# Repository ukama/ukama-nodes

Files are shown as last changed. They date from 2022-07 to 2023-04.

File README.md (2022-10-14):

# ukama-nodes
This repo contains all of the Ukama hardware stuff. This includes the products, modules there in and instruction on how to build one. 

Currently the repo is organized as "electronics", "mechanics" and "products" 

## Electronics:

This contains all the electronics board (PCBs) used in various Ukama products. Currently, the electronics includes:

gpp - general purpose processing board (use in Tower Node)

ctrl - Controller board for the FE (front-end) (use in Amplifier Unit) 

fe - front-end (use in Amplifier Unit)

mask - add-on extension board for the Tower Node

mini_trx - small RAN (base-station) and is used in Home Node

trx - RAN and is used in Tower Node

Each of the eletronics has assembly, BoM, layout, placement, schematic and stencil info. 

## Mechanics:

This contains all the mechanics (CADs) for all of the Ukama products. Currently. it includes the assembly, CAD, drawings, heatsinks (if any) and gaskets (if any). 

## Products:

This contains all the product level information. This include, currently, the system-level BoM and artwork (if any.)

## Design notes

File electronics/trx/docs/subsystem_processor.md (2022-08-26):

#### Processor

LTE-SoC processor used in TRX module is CNF7130 from Marvell. It is MIPS64 based Quad core System-on-chip with below features: 
* Core frequency up to 1.3GHz and Co-processor frequency up to 800MHz
* High-bandwidth fully coherent on-chip memory system including a 1MB 16-way set-associative L2 cache
* A 72-bit DDR3 DRAM interface, up to 1066 MHz data rate
* Integrated Baseband processing module containing three radio-processing clusters: 
    * An uplink symbol radio-processing cluster, 
    * An uplink soft-bit radio processing cluster, 
    * A downlink radio processing cluster

Below diagram provides high level information about internal modules of LTE-SoC:

processor

The Local Memory Controller (LMC) DDR3 SDRAM controller conforms to the JEDEC DDR3 SDRAM specification. 
Up to 32GB DDR3 RAMs can be connected to LMC SDRAM controller. In TRX module, 4GB DDR3 RAM is used with Data rates up to 1066 MHz.

The Level-2 Cache Controller (L2C) has shared on-chip cache memory which is shared be all of the cores and I/O components on LTE-SOC. 

Shared main memory (implemented via the level-2 cache and the DRAM) is the primary communication media for bulk transfers in the LTE-SoC. 

Level-2 cache is shared by all of the CPU cores instructions/data and hardware device DMA accesses. The L2 cache can be partitioned, and can be bypassed on a reference-by-reference basis. I/O devices can DMA data directly into L2 cache.

##### LTE-SoC Internal Clock Architecture

LTE-SoC has a single reference clock signal (PLL_REF_CLK) that feeds into three PLLs (Core PLL, Co-processor PLL and DDR PLL) that provide the clock signals for the rest of the chip.
Each PLL has its own set of PLL_REF_CLK multipliers, allowing each to generate its own frequency.

The Core PLL generates the core clock, which is used by the MIPS cores. The frequency is configured by using pin straps during Reset release. PLL_MUL_[4:0] pins are used as below: 

| PLL_MUL[4:0] | Clock Frequency |
|---|---|
| 0x02 | 400MHz |
| 0x06 | 600MHz |
| 0x0A | 800MHz |
| 0x0E | 1.0GHz |
All other options are reserved

The Coprocessor PLL generates the coprocessor clock, which is used by the rest of the coprocessors and the I/O interfaces. The frequency is determined by pin straps connected to SYS_PLL_MUL_[4:0] pins and are listed as below:

| SYS_PLL_MU[4:0] | Clock Frequency |
|---|---|
| 0x02 | 400MHz |
| 0x06 | 600MHz |
| 0x0A | 800MHz |
All other options are reserved

Below diagram shows the internal clock scheme of LTE-SoC:

processor-clock

Notes:-
      w : SMI_CLK[PHASE]  

QLM0 Serdes clock will be derived from an external source. In TRX module, a spread spectrum clock generator IC is used as source which will produce a clock of 100MHz.

Whereas, QLM1 Serdes clock can be either derived from an external source or from QLO0 reference clock. In TRX module, QLM0 reference clock is used to source QLM1 Serdes also. 

USB PLL will have a dedicated crystal connected to its  XO and XI pins.

Note that the core clock, the coprocessor clock, the DDR3 clock, and the PCIe interface have the following interdependencies:
* the core-clock frequency must be greater than or equal to the coprocessor-clock frequency
* the core-clock frequency must be greater than or equal to the DDR3-clock frequency
* PCIe Gen II requires a coprocessor-clock frequency of 600 MHz.

##### Boot process

LTE-SoC implements a boot-bus interface that can be interfaced with NOR, eMMC, or SD flash devices. In TRX module, NOR flash is used as primary boot device and eMMC memory is used as additional storage device. 
There are 8 Chip selects and 32bit Address/Data lines in boot bus.
When configured in 8bit data width option, BOOT_AD[31:24] is the data bus.
The boot bus consumes a 4GB portion of the LTE-SoC physical-address (PA) space range from 0x1 0000 0000 0000 to 0x1 0000 FFFF FFFF. 
In TRX module, Chip select 0 (CE_0) is connected to NOR Flash for primary booting purpose. 
LTE-SoC maps PA space to 0x1 0000 1FC0 0000 for CE_0.
Boot code should be present in the NOR flash starting at boot address 0. When the LTE-SoC self-boots, core 0 executes this code immediately following chip-reset de-assertion. 
The pin straps that LTE-SoC uses for configuration are shown below:
| Pin Strap | Comment |
|---|---|
| BOOT_AD[15] | An external pull-up resistor changes region 0 from nonmultiplexed (i.e. nonALE mode) to multiplexed (i.e. ALE) mode. |
| BOOT_AD[14] | An external pull-up resistor changes region 0 from eight-bit data width to 16-bit data width |
| BOOT_AD[12] | An external pull-up resistor changes the default polarity of BOOT_DMACK1 from active-high to active-low |
| BOOT_AD[11] | An external pull-up resistor changes the default polarity of BOOT_DMACK0 from active-high to active-low |
| BOOT_AD[10:9] | External pull-up resistors that change the boot-bus-driver drive strength in the following manner: <br /> [00] : Full strength <br /> [01] : 20 ohm <br /> [10] : 50 ohm <br /> [11] : 60 ohm |
| BOOT_AD[8] | When an external pull-down resistor is connected, SoC will boot from NOR Flash |
| BOOT_AD[7:0]  | When using eMMC, BOOT_AD[7:0] is EMMC_DAT[7:0]. |

##### GPIO 

The GPIO bus is a collection of general-purpose pins that can be configured for various tasks, and is a low-speed bus. Each pin can be configured as input, output, clock-like output, level-sensitive/edge-triggered interrupt pins. 

In TRX module, GPIO's are used for different purposes as listed in below table : 

| GPIO # | DIR  | Default state | Connected to | Functionality |
|:---:|:---:|:---:|:---:|:---:|
| 0 | Out  | 1 | LED | General purpose LED |
| 1 | In | 0 | Temperature Sensor | Critical temperature alert |
| 2 | Out  | 1 | JTAG header | JTAG Soft reset |
| 3 | Out  | 0 | Ethernet Switch  | Ethernet SYNCE |
| 4 | In | 0 | GPS module | GPS time pulse |
| 5 | Out  | 0 | Watchdog timer | Watchdog Input |
| 6 | In | 0 | COM module | Power good of COM module |
| 7 | In | 0 | Mask module | Interrupt from Mask module |
| 8 | Out  | 0 | eMMC | Dedicated pin to enable eMMC |
| 9 | In | 0 | Switch | High indicates LTE-SoC is I2C master<br> Low indicates COM module is I2C master |
| 10 | In/Out | 0 | COM module | General purpose I/Os from COM module |
| 11 | In | 0 | Connector | External 1pps reference input |
| 12 | Out  | 0 | COM module | COM module power recycle |
| 13 | In/Out | 0 | COM module | General purpose I/Os from COM module |
| 14 | In/Out | 0 | COM module | General purpose I/Os from COM module |
| 15 | In | 0 | COM module | Platform Reset information from COM module |
| 16 | In | 0 | I2C switch | TRX module I2C interrupt |
| 17 | In | 0 | COM module | COM module I2C interrupt |
| 18 | In | 1 | Reset switch | Push button reset input |
| 19 | Out  | 1 | Reset | System reset out from LTE-SoC |

##### Debug

LTE-SoC has multiple debug features, including:
* Two UARTs for connection to an external console.
* Full core support for the MIPS EJTAG standard, including single-step and an external JTAG interface with one internal TAP controller per core.

In TRX module, a provision is been made to connect EJTAG connector. 
Main debug port is UART0. Boot logs during system boot will be transmitted through UART0 port at 115200 baud rate. 
TX and RX pins of UART0 is connected to an isolator and then connected to USB to UART converter IC to have a mini-B USB connector as debug port.
The 5V required by the converter IC is derived from the USB connector. 

Optionally, UART1 signals are also brought to a 3 pin header. 

processor-debug

##### SerDes

The PCIe and SGMII interfaces are shared SerDes interfaces of LTE-SoC. The SerDes interface is made up of two two-lane modules (DLM0 and DLM1). 
The DLMs have the following configurations:
* DLM0: 2× SGMII/1000 Base-X
* DLM1: PCIe (one ×2 or 2 ×1)

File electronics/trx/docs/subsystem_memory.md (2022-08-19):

###Memory Sub-system

####DDR RAM

The LTE-SoC has an internal LMC DDR3 SDRAM controller which conforms to the JEDEC DDR3 SDRAM specification. A total of 4 DDR3 ICs, with 512MB density each are connected to provide a memory capacity of 4GB. One additional DDR3 IC is provided for SECDED ECC purpose. 

DDR3 memory architecture is as shown below: 

DDR

DDR subsystem operates at a voltage of 1.35V. 72bit (64bit data + 8bit ECC) bus is configured to work with data transfer rate at 1066MHz.

Below table lists out different DDR signals and their functionality:

| Signal Name | Direction  | Description |
|---|---|---|
| **_ Rank 0 – Data Signal Group _** | | |
| DDR_DQ[63:0] | In/Out | Data Bus |
| DDR_DQSP[7:0], DRAM0_DQSN[7:0] | In/Out | Data Strobes |
| DDR_CB[7:0] | In/Out | ECC Data Bits |
| DDR_CBS0P, DDR_CBS0N | In/Out | ECC Data Strobes |
| **_ Rank 0 – Command Signal Group _** | | |
| DDR_A[15:0] | Out | Memory Address Bus |
| DDR_BA[2:0] | Out | Bank Select |
| DDR_RAS# | Out | Row Address Select |
| DDR_CAS# | Out | Column Address Select |
| DDR_WE# | Out | Write Enable |
| **_ Rank 0 – Control Signal Group _** | | |
| DDR_DIMM0_CS0_L | Out | Chip Select (one per rank) |
| DDR_DIMM0_CKE0 | Out | Clock Enable (one per rank). |
| DDR_DIMM0_ODT0 | Out | On-Die Termination Select/Enable |
| **_ Rank 0 – Clock Signal Group _** | | |
| DDR_CK0P | Out | Differential Clocks |
| DDR_CK0N | Out | Inverted Differential Clocks |
| **_ DDR3L Reference and Compensation Signals _** | | |
| DDR_VREF | In | SDRAM Reference Voltage: external reference voltage input for each system margining |
| DDR_PLL_VDD33 | In | DDR3L Power Good Monitor. |
| DDR_RESET_L | Out | DDR3L DRAM Reset. |
| DDR_COMP_DP DDR_COMP_DN | In/Out | DDR3L Compensation signals |

The termination scheme for DDR signals is as shown below:

DDR Termination

#### NOR Flash

TRX module is equipped with a 128MB parallel NOR flash which is configured as primary boot device. This Asynchronous memory will work with a supply voltage of 3.3V. 

Below diagram illustrates the NOR flash connection with LTE-SoC:

NOR

Voltage compatibility of NOR flash with LTE-SoC is as follows:

##### High Level Noise Margin:

| Source  | Destination  | Voh (min) | Vih (min) | Noise margin  |
|---|---|---|---|---|
| LTE-SOC | NOR flash | 2.6 | 2.31 | 0.29 |

##### Low Level Noise Margin:
| Source | Destination | Vol (max) | Vil (max) | Noise margin |
|---|---|---|---|---|
| LTE-SOC | NOR flash | 0.7 | 0.8 | 0.1 |

##### High Level Noise Margin:
| Source | Destination | Voh (min) | Vih (min) | Noise margin |
|---|---|---|---|---|
| NOR flash | LTE-SOC | 2.805 | 2.31 | 0.495 |

##### Low Level Noise Margin:
| Source | Destination | Vol (max) | Vil (max) | Noise margin |
|---|---|---|---|---|
| NOR flash | LTE-SOC | 0.495 | 0.825 | 0.33 |

##### High Level Noise Margin:
| Source | Destination | Voh (min) | Vih (min) | Noise margin |
|---|---|---|---|---|
| LTE-SOC | Latch | 2.6 | 2.0 | 0.6 |

##### Low Level Noise Margin:
| Source | Destination | Vol (max) | Vil (max) | Noise margin |
|---|---|---|---|---|
| LTE-SOC | Latch | 0.7 | 0.8 | 0.1 |

##### High Level Noise Margin:
| Source | Destination | Voh (min) | Vih (min) | Noise margin |
|---|---|---|---|---|
| Latch | NOR flash | 3.1 | 2.31 | 0.79 |

##### Low Level Noise Margin:
| Source | Destination | Vol (max) | Vil (max) | Noise margin |
|---|---|---|---|---|
| Latch | NOR flash | 0.55 | 0.8 | 0.25 |

#### eMMC

Additional storage option is provided in TRX module in the form of eMMC memory IC which is complaint with eMMC Specification Ver 5.1. 

eMMC memory architecture is as shown below:

eMMC

Data bus of eMMC IC is connected to LTE-SoC via shared boot bus. Clock signal is derived from CE_5 pin of LTE-SoC and Command signal is derived from CE_1 pin of LTE-SoC

All the MMC signals are connected to eMMC device via a FET Switch which acts as level shifter and is enabled through GPIO_8 from LTE-SoC. 
A Complimentary pair enhancement mode MOSFET is used to control the power supply of eMMC which is also driven from GPIO_8 from LTE-SoC.

Voltage compatibility of eMMC with LTE-SoC is as follows:

##### High Level Noise Margin:

| Source  | Destination  | Voh (min) | Vih (min) | Noise margin  |
|---|---|---|---|---|
| LTE-SOC | FET Switch | 2.6 | 2.31 | 0.29 |

##### Low Level Noise Margin:
| Source | Destination | Vol (max) | Vil (max) | Noise margin |
|---|---|---|---|---|
| LTE-SOC | FET Switch | 0.7 | 0.8 | 0.1 |

##### High Level Noise Margin:
| Source | Destination | Voh (min) | Vih (min) | Noise margin |
|---|---|---|---|---|
| FET Switch | LTE-SOC | 2.805 | 2.31 | 0.495 |

##### Low Level Noise Margin:
| Source | Destination | Vol (max) | Vil (max) | Noise margin |
|---|---|---|---|---|
| FET Switch | LTE-SOC | 0.495 | 0.825 | 0.33 |

##### High Level Noise Margin:
| Source | Destination | Voh (min) | Vih (min) | Noise margin |
|---|---|---|---|---|
| FET Switch | eMMC | 2.6 | 2.0 | 0.6 |

##### Low Level Noise Margin:
| Source | Destination | Vol (max) | Vil (max) | Noise margin |
|---|---|---|---|---|
| FET Switch | eMMC | 0.7 | 0.8 | 0.1 |

##### High Level Noise Margin:
| Source | Destination | Voh (min) | Vih (min) | Noise margin |
|---|---|---|---|---|
| eMMC | FET Switch | 3.1 | 2.31 | 0.79 |

##### Low Level Noise Margin:
| Source | Destination | Vol (max) | Vil (max) | Noise margin |
|---|---|---|---|---|
| eMMC | FET Switch | 0.55 | 0.8 | 0.25 |

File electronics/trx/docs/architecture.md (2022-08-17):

####Architecture overview

TRX module is based on a LTE-SoC along with RF Transceiver. 
Below diagram represents the high level architecture overview of TRX module: 

high level architecture diagram 

A detailed representation of TRX module subsystems along with their interfaces is as shown below:

detailed architecture diagram

CNF7130 from Marvell is used as LTE-SoC in TRX module. It will have 4GB DDR3 memory as RAM connected via DDR3 bus of LTE-SoC, 128MB NOR Flash and 32GB eMMC memories connected to Boot bus of LTE-SOC acts as storage devices. 
AD9363 from Analog is used as RF Transceiver which is connected to LTE-SoC via two ports of 12bit data bus along with control signals. 
An Ethernet switch from Marvell 88E6341, acts as bridge between LTE-SoC, COM Module and External RJ45 connector. 
A GPS module and an OCXO along with DAC are used to cater for timing requirements of TRX module.

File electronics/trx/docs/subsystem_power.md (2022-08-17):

###Power overview

####Power tree

TRX module is powered with IEEE 802.3bt Type 4 Class 8 PoE. A PD controller is used along with dual ideal diode bridge controller to receive power from  data/spare pairs of ethernet cable. PD controller is configured to convert 50-57V of PoE supply to 12V DC supply which will be input supply for the TowerNode system. A provision of connecting DC supply from external power source is also made. In scenarios where both PoE and external DC supply are connected, system will disable PoE and considers external DC supply only. 

Below diagram represents the power architecture of TRX module:

power tree

Input supply,12V goes through a PMBus/I2C complaint controller to measure, protect and control the electrical operating conditions. 
Protected 12V supply is provided to COM module, mask module and is also converted to 5V from a step-down DC/DC converter. 5V is then converted to various supplies like 3.3V through a step down converter, 1.1V for LTE-SoC through a buck converter and 1.35V for LTE-SoC through a step down converter. 
3.3V is a major supply for TRX module and is used for LTE-SoC, NOR Flash, eMMC, Ethernet PHY, OCXO, GPS module, sensors and EEPROMs. Secondary supplies of LTE-SoC such as 1.5V, 1.8V and VTT supply for DDR memories are generated from 3.3V supply through voltage regulators. 1.8V is further converted to 1.3V required for RF Transceiver through a LDO. 

####Power Sequence

Power sequence of TRX module is as shown below: 

--Power sequence diagram to be inserted here -- 

High level Power sequence followed in TRX module design is in the order of System supplies -> LTE-SoC -> DDR -> System Reset release. 

System input supply 12V is converted to 5V initially with a time delay of 10ms. The step-down converter used to convert 5V to 3.3V will have a delay of 5ms. 
Once 3.3V is stable, the 3.3V power good signal asserted from step-down converter will drive enable pins of buck/dtep-down converters of LTE-SoC power supplies(1.8V, 1.5V and 1.1V). 

A stable 1.1V will assert power good signal from buck converter which is used to enable remaining power supplies of LTE-SoC (1.35V and VTT).

The 1.35V power good is then delayed by 150ms to ensure LTE-SoC and other peripherals are in powered-up state before releasing the Reset. 

####Power Dissipation

Below table lists out the maximum power dissipated by major ICs in TRX module: 

| Sl.No. | Component P/N | Description | Manufacturer | Power (W) |
|---|---|---|---|---|
| 1 | CNF7130-1000BG772-G | Cavium OCTEON Fusion CNF7130 | Cavium | 18 |
| 2 | IS43TR16256AL-15HBLI-ND | 4Gbit DDR3L SDRAM, FBGA 96 | ISSI | 0.405 |
| 3 | IS43TR16256AL-15HBLI-ND | 4Gbit DDR3L SDRAM, FBGA 96 | ISSI | 0.405 |
| 4 | IS43TR16256AL-15HBLI-ND | 4Gbit DDR3L SDRAM, FBGA 96 | ISSI | 0.405 |
| 5 | IS43TR16256AL-15HBLI-ND | 4Gbit DDR3L SDRAM, FBGA 96 | ISSI | 0.405 |
| 6 | IS43TR16256AL-15HBLI-ND | 4Gbit DDR3L SDRAM, FBGA 96 | ISSI | 0.405 |
| 7 | 88E6341 | Gigabit Energy Switch | Marvell | 0.726 |
| 8 | MLC1260-401MLB | Fixed Inductors Power Inductor 0.4 uH 20 % | Coilcraft | 0.103 |
| 9 | VLF10045T-2R2N7R4 | INDUCTOR POWER 2.2UH 6.3A SMD,±30% | TDK | 0.1632 |
| 10 | ASPI-0530HI-1R5M-T2 | INDUCTOR POWER 1.5UH 5A SMD +/-20% | Abracon Corporation | 0.125 |
| 11 | PI6C557-03BLE | IC CLOCK GENERATOR 16TSSOP | Pericom | 0.33 |
| 12 | TPS53353DQPT | IC REG BUCK SYNC ADJ 20A 22 pin QFN | TI | 0.55 |
| 13 | TPS54620RGYR | Synchronous Step-down Voltage Converter 6A | TI | 1.08 |
| 14 | AP3418KTR-G1 | 1500mA Step-Down Regulator Adjustable | Diodes Inc | 0.1125 |
| 15 | TPS54519RTET | IC REG BUCK SYNC ADJ 5A 16WQFN | TI | 0.72 |
| 16 | BGA824N6 | The BGA824N6 is a front-end low noise amplifier | infineon | 0.198 |
| 17 | AD9363ABCZ | RF Transceiver | Analog Device | 1.874 |
| 18 | LTM8056EY#PBF | IC MOD BUCK REG 58VIN 121BGA | Linear Technology | 3.5 |
| 19 | LMZ14203HTZX/NOPB | IC BUCK SYNC ADJ 3A TO-PMOD-7 | TI | 1.3 |
| 20 | TPS7A7300RGWR | IC REG LDO FIX/ADJ 3A 20VQFN | TI | 0.96 |
| 21 | TPS7A7300RGWR | IC REG LDO FIX/ADJ 3A 20VQFN | TI | 0.32 |
| 22 | TPS7A7300RGWR | IC REG LDO FIX/ADJ 3A 20VQFN | TI | 1.19 |

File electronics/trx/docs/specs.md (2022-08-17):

####Operational requirements
TRX Board along with a COM board comprises as TowerNode system. The TowerNode system is designed to meet the following requirements:

•	Powered by IEEE 802.3bt PoE (71.3 Watt Max)
•	Interface to the backhaul is over a RJ45 (Gigabit Ethernet) interface
•	Interface to the RF Front End (AmplifierNode) through cables connected over the SMA connector
•	Maximum RF output from TowerNode is -14dBm

####Environmental requirements
The TowerNode system is designed to operate at below environmental conditions

•	Ambient temperature: -20 °C to +50 °C
•	Altitude: Up to 20,000 feet
•	Solar load: Max 1100W/m2

####Hardware features
•	TowerNode is compliant with IEEE 802.3bt standard Powered Device with maximum power rating of 71.3W. 
•	TowerNode system architecture comprises of two modules: TRX and COM
•	TRX module is based on a LTE-SoC from Marvell which is used for Baseband processing
•	LTE-SoC is a quad core MIPS64 processor with Uplink/Downlink hardware accelerators
•	TRX module has below memory options:
  --	4GB DDR3L as RAM memory
  --	128MB NOR Flash as boot storage
  --	32GB eMMC as main storage
  --	Two 256Kb EEPROMs for configuration and inventory purposes

•	TRX module will have a default configuration switch that will enable the user to reset the Tower Node to factory settings.
•	A push button reset provision is provided on TRX module for user to perform system reset or to reset the Tower Node to factory defaults state.
•	TRX module will have several temperature sensors to enable measuring of temperature near the hot spots.
•	There are four RGB LEDs provided to indicate the status of the system as per implementation. 
•	TRX module is protected for over voltage, under voltage, over current, ESD
•	A generic GPS module is accommodated for timing requirements. 
•	Optional Mask module can be connected to TRX module via mask connector based on the system requirements. Different types of Mask module can be used such as Connectivity, Storage etc.

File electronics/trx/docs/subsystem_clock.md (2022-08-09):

###Clock/Reset Overview

####Clock tree

Several clock sources are used in TRX module to cater for clock requirements of the system. Below diagram represents the clock architecture used in TRX module:

---Clock tree to be inserted -- 

Oscillators are used as core clock reference for CNF7130, Ethernet switch and Clock generator IC. 
A 12MHz crystal is used as USB reference clock for CNF7130
In order to support timing requirement of AD9363, an OCXO,U7769LF is used from Rakon. This can be tuned via an analog signal at control voltage input pin. Analog voltage is generated by using a DAC(DAC8571) controlled from CNF7130

####Reset tree

Reset architecture used in TRX module is as shown below:

--Reset tree to be inserted--

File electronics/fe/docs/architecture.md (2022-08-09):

##Transmitter test case procedure
1.	Set the BS as per the test setup as per the setup diagram shown above.
2.	Start with 10MHz channel bandwidth for Top, Middle and Bottom channel frequency.
3.	Configure the board TRX switching by enabling TX mode (by making TRX_SWIT_CNTRL High)
4.	Run the command “./dl_pltd.sh 1 0001 1.1 2” to transmit signal according to ETM 1.1 test model.
5.	Measure the mean output power from spectrum analyzer.

Run the scipi command to measure the Mean output power from spectrum analyzer 
Commands need to update
6.	Repeat the above test steps for Middle and Bottom channel frequencies.
7.	Repeat the above test steps for the Antenna port 1.
8.	Ensure the test results (power level, ACLR, SEM) is as per the test requirement as per expected.
9.	SEM test case setup need to update.

| Sl.No. | Description | PartNumber | Qty | Value |
|---|---|---|-----|---|
| 1 | | | | |
| 2 | | | | |
| | | | | |

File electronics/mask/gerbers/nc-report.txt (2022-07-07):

(---------------------------------------------------------------------)
(                                                                     )
(    NC DRILL Log                                                     )
(                                                                     )
(    Drawing          : #Taaaaai09524.tmp                             )
(    Software Version : 16.6P004                                      )
(    Date/Time        : Mon May 16 22:51:13 2022                      )
(                                                                     )
(---------------------------------------------------------------------)

 Processing NC Parameters file 'nc_param.txt' ...

 NC PARAMETERS
 -------------

 FORMAT   		5.5
 MACHINE-OFFSET		x:0.000000	y:0.000000
 FEEDRATE		1
 COORDINATES		ABSOLUTE
 OUTPUT-UNITS		ENGLISH
 TOOL-ORDER		INCREASING
 REPEAT-CODES		YES
 SUPPRESS-LEAD-ZEROES	NO
 SUPPRESS-TRAIL-ZEROES	NO
 SUPPRESS-EQUAL		NO
 TOOL-SELECT		YES
 HEADER			none
 LEADER			12
 CODE			ASCII
 SEPARATE		NO
 SEPARATE-ROUTING	NO
 OPTIMIZE_DRILLING	NO
 ENHANCED_EXCELLON	YES
 SCALE			1.000000

 WARNING(SPMHMF-358): Design precision is the same as that of the drill output file data.
 WARNING(SPMHMF-359): Data rounding errors may still be possible.
 WARNING(SPMHMF-368): Cannot find NC Drill tool file 'nc_tools.txt'
 WARNING(SPMHMF-369): ... will auto-generate tool file 'nc_tools_auto.txt'.

     Auto-generating tool file 'nc_tools_auto.txt' ...

           Size  Plating  Tool        + Tolerance  - Tolerance

          10.00  P        T01            3.000000     3.000000
          39.37  P        T02            3.000000     3.000000
          39.40  P        T03            3.000000     3.000000
          42.91  P        T04            0.000000     0.000000
          47.20  P        T05            3.000000     3.000000
          55.12  P        T06            3.000000     3.000000
          62.99  P        T07            3.000000     3.000000
         145.70  P        T08            3.000000     3.000000
          20.00  N        T09            3.000000     3.000000
          43.00  N        T10            3.000000     3.000000
          44.00  N        T11            3.150000     3.150000
          64.00  N        T12            1.970000     1.970000

 Drill files being output to directory 'E:/Mask Board/WORK/16-05-22' ...

     'mask-C2-RevC-1-4.drl' created for holes connecting TOP and BOTTOM
     ------------------------------------------------------------------

     Tool  Num     Size      +/- Tolerance     Plating   Quantity

     T01    1.  10.0000    3.0000/  3.0000      PLATED        551
     T02    2.  39.3700    3.0000/  3.0000      PLATED          2
     T03    3.  39.4000    3.0000/  3.0000      PLATED          4
     T04    4.  42.9100    0.0000/  0.0000      PLATED          5
     T05    5.  47.2000    3.0000/  3.0000      PLATED          4
     T06    6.  55.1200    3.0000/  3.0000      PLATED          4
     T07    7.  62.9900    3.0000/  3.0000      PLATED          4
     T08    8. 145.7000    3.0000/  3.0000      PLATED          3
     T09    9.  20.0000    3.0000/  3.0000  NON_PLATED          8
     T10   10.  43.0000    3.0000/  3.0000  NON_PLATED          8
     T11   11.  44.0000    3.1500/  3.1500  NON_PLATED          4
     T12   12.  64.0000    1.9700/  1.9700  NON_PLATED          4

     ---- Total holes:                                        601

     ---- Total head travel:              35.58 feet (10.85 meters)

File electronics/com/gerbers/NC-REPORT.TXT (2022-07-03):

(---------------------------------------------------------------------)
(                                                                     )
(    NC DRILL Log                                                     )
(                                                                     )
(    Drawing          : COM_V1_P2_21-12-2020_4.brd                    )
(    Software Version : 16.6-2015S108                                 )
(    Date/Time        : Fri Dec 25 11:43:52 2020                      )
(                                                                     )
(---------------------------------------------------------------------)

 Processing NC Parameters file 'nc_param.txt' ...

 NC PARAMETERS
 -------------

 FORMAT   		5.5
 MACHINE-OFFSET		x:0.00000	y:0.00000   (inch)
 FEEDRATE		1
 COORDINATES		ABSOLUTE
 OUTPUT-UNITS		ENGLISH
 TOOL-ORDER		INCREASING
 REPEAT-CODES		YES
 SUPPRESS-LEAD-ZEROES	NO
 SUPPRESS-TRAIL-ZEROES	NO
 SUPPRESS-EQUAL		NO
 TOOL-SELECT		YES
 HEADER			none
 LEADER			12
 CODE			ASCII
 SEPARATE		NO
 SEPARATE-ROUTING	NO
 OPTIMIZE_DRILLING	NO
 ENHANCED_EXCELLON	YES
 SCALE			1.000000

 WARNING(SPMHMF-360): Design precision is greater than that of the drill output file data.
 WARNING(SPMHMF-361): Data rounding errors are very possible.
 WARNING(SPMHMF-368): Cannot find NC Drill tool file 'nc_tools.txt'
 WARNING(SPMHMF-369): ... will auto-generate tool file 'nc_tools_auto.txt'.

     Auto-generating tool file 'nc_tools_auto.txt' ...

           Size  Plating  Tool        + Tolerance  - Tolerance

          8.000  P        T01            3.000000     3.000000
         10.000  P        T02            3.000000     3.000000
         12.000  P        T03            3.000000     3.000000
         39.370  P        T04            3.000000     3.000000
         43.000  P        T05            3.000000     3.000000
         47.244  P        T06            3.000000     3.000000
        145.669  P        T07            3.000000     3.000000
         19.685  N        T08            3.150000     3.150000

 Drill files being output to directory 'E:/CAD/CAD/FACEBOOK/COM V1/WORK/21-12-20' ...

     'COM_V1_P2-1-10.drl' created for holes connecting TOP and BOTTOM
     ----------------------------------------------------------------

     Tool  Num     Size      +/- Tolerance     Plating   Quantity

     T01    1.   8.0000    3.0000/  3.0000      PLATED       2348
     T02    2.  10.0000    3.0000/  3.0000      PLATED         75
     T03    3.  12.0000    3.0000/  3.0000      PLATED         99
     T04    4.  39.3700    3.0000/  3.0000      PLATED          4
     T05    5.  43.0000    3.0000/  3.0000      PLATED          2
     T06    6.  47.2440    3.0000/  3.0000      PLATED          4
     T07    7. 145.6690    3.0000/  3.0000      PLATED          6
     T08    8.  19.6850    3.1500/  3.1500  NON_PLATED         24

     ---- Total holes:                                       2562

     ---- Total head travel:              155.52 feet (47.40 meters)

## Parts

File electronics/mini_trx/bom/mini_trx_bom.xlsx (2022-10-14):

Item | Quantity | Reference | Part Number | Manufacturer | Description | Value
1 | 3 | C1,C5,C19 | 202R18W102KV4E | Johanson Dielectrics Inc. | CAP CER 1000PF 2KV X7R 1206 | 1000PF
2 | 2 | C3,C4 | 101X43W474MV4E | Johanson Dielectrics Inc | CAP CER 0.47UF 100V X7R 1812 | 0.47UF
3 | 229 | C6,C25,C31,C41,C57,C58,C59,C60,C61,C63,C64,C65,C66,C67,C68,C69,C70,C71,C72,C73,C74,C75,C81,C82,C83,C84,C85,C86,C87,C88,C89,C90,C92,C97,C98,C99,C100,C101,C102,C103,C104,C105,C107,C108,C109,C110,C112,C113,C114,C115,C116,C117,C118,C119,C120,C121,C122,C123,C124,C125,C126,C127,C128,C129,C130,C135,C136,C137,C138,C139,C154,C157,C158,C163,C164,C165,C176,C181,C182,C202,C204,C210,C214,C243,C244,C247,C248,C251,C254,C255,C256,C258,C259,C263,C264,C269,C271,C272,C274,C275,C277,C278,C279,C280,C281,C282,C283,C286,C287,C288,C289,C290,C291,C292,C294,C296,C297,C298,C299,C302,C303,C304,C305,C306,C307,C308,C309,C310,C311,C312,C313,C314,C315,C316,C317,C318,C324,C325,C326,C327,C328,C329,C330,C332,C333,C334,C335,C336,C337,C338,C339,C340,C341,C342,C343,C344,C346,C347,C348,C349,C350,C351,C352,C353,C354,C355,C356,C357,C358,C359,C360,C361,C362,C363,C364,C365,C366,C369,C373,C378,C388,C389,C390,C391,C392,C401,C402,C403,C404,C405,C406,C407,C408,C413,C415,C418,C420,C423,C424,C428,C429,C431,C432,C433,C434,C435,C438,C439,C459,C462,C604,C605,C616,C619,C621,C622,C623,C624,C625,C628,C629,C630,C631,C632,C633,C634,C637,C638,C639 | C1005X7R1E104K050BB | TDK Corporation | CAP CER 0.1UF 25V 10% X7R 0402 | 0.1uF
4 | 72 | C26,C43,C76,C95,C96,C106,C111,C134,C141,C156,C159,C160,C166,C167,C168,C170,C177,C178,C179,C200,C238,C239,C241,C249,C252,C257,C260,C261,C262,C268,C270,C273,C293,C319,C320,C321,C322,C323,C331,C345,C367,C371,C380,C383,C393,C394,C396,C398,C410,C412,C414,C421,C430,C437,C440,C445,C446,C448,C449,C450,C461,C464,C601,C602,C603,C617,C618,C620,C627,C636,C641,C659 | GRM188C81C106MA73D | Murata | CAP CER 10UF 16V X6S 0603 | 10uF
5 | 6 | C28,C52,C53,C54,C55,C400 | GRM31CR60J107ME39L | Murata Electronics | CAP CER 100UF 6.3V 20% X5R 1206 | 100uF/6.3V
6 | 7 | C29,C77,C203,C225,C226,C411,C417 | GRM188R61A226ME15D | Murata Electronics | CAP CER 22UF 10V 20% X5R 0603 | 22uF/10V
7 | 3 | C30,C94,C436 | CC0402KRX7R7BB103 | Yageo | CAP CER 10000PF 16V 10% X7R 0402 | 10nF
8 | 12 | C35,C131,C132,C140,C144,C145,C171,C399,C409,C416,C456,C606 | CC0402KRX7R8BB102 | Yageo | CAP CER 1000PF 25V X7R 0402 | 1000pF
9 | 15 | C37,C152,C169,C172,C211,C276,C395,C397,C611,C612,C613,C614,C626,C635,C640 | CC0402KRX5R8BB105 | Yageo | CAP CER 1UF 25V X5R 0402 | 1uF
10 | 2 | C40,C222 | GRT155R61E474ME01D | Murata Electronics | CAP CER 0.47UF 25V X5R 0402 | 0.47uF
11 | 1 | C48 | TMK325ABJ476MM-P | Taiyo Yuden | CAP CER 47UF 25V X5R 1210 | 47uF/25V
12 | 1 | C49 | TPSE687K006R0045 | AVX Corporation | CAP TANT 680UF 10% 6.3V 2917 | 680uF
13 | 2 | C62,C79 | C0402C220J3GACTU | KEMET | CAP CER 22PF 25V C0G/NP0 0402 | 22pF
14 | 6 | C80,C91,C284,C455,C600,C615 | GRM1555C1H200JA01D | MURATA | CAP CER 20PF 50V 5% NPO 0402 | 20pF
15 | 1 | C93 | CC0402KRX7R8BB102 | Yageo | CAP 1000PF 25V CERAMIC 0402 SMD | 1000pF
16 | 14 | C146,C147,C149,C150,C161,C162,C173,C174,C422,C425,C426,C427,C465,C466 | C0402C330J4RACAUTO | KEMET | CAP CER 0402 33PF 16V X7R 5% AUT | 33pF
17 | 1 | C201 | C0402C182J3GAC7867 | KEMET | CAP CER 1800PF 25V NP0 0402 | 1.8nF
18 | 2 | C206,C651 | GRM033R61C104KE84D | Murata Electronics | CAP CER 0.1UF 16V X5R 0201 | 0.1uF
19 | 1 | C215 | CC0402KRX7R7BB222 | Yageo | CAP CER 2200PF 16V X7R 0402 | 2.2nF
20 | 1 | C220 | GRM155R61E225ME15D | Murata Electronics | CAP CER 2.2UF 25V X5R 0402 | 2.2uF
21 | 1 | C231 | EEE-FK1A221XP | Panasonic | CAP TANT 680UF 4V 10% LOESR SMD | 220uF/10V
22 | 4 | C245,C246,C250,C253 | CC0402KRX7R8BB102 | Yageo | CAP 10000PF 16V CERAMIC 0402 SMD | 1000pF
23 | 1 | C266 | CC0402KRX7R8BB332 | YAGEO | CAP CER 3300PF 25V X7R 0402 | 3.3nF
24 | 1 | C368 | GRM155C81E105KE11D | Murata | CAP CER 1UF 25V X6S 0402 | 1UFX_16V
25 | 13 | C370,C372,C374,C375,C376,C377,C379,C381,C382,C384,C385,C386,C387 | GRM033R61E104ME14D | Murata Electronics North America | CAP CER 0.1UF 25V X5R 0201 | 0.1UFX
26 | 1 | C419 | 04023A3R3CAT2A | AVX Corporation | CAP CER 3.3PF 25V NP0 0402 | 3.3pF
27 | 4 | C442,C443,C458,C463 | C0402C101K3RAC7867 | KEMET | CAP CER 100PF 25V X7R 0402 | 100pF
28 | 50 | R10,R2N1,R2N2,L42,L43,R108,R120,R121,R160,R166,R180,R184,R199,R201,R233,R234,R239,R241,R288,R300,R370,R372,R378,R384,R395,R401,R409,R414,R439,R444,R445,C453,C454,R465,R466,R468,R469,R470,R471,R472,R473,R561,R562,R565,R566,R606,R614,R616,R619,R620 | RC0402JR-070RL | Yageo | RES SMD 0 OHM JUMPER 1/16W 0402 | 0
29 | 2 | C607,C609 | EMVE250ADA470MF55G | United Chemi-Con | CAP ALUM 47UF 20% 25V SMD | 47uF
30 | 1 | C608 | CC0201KRX5R8BB103 | Yageo | CAP CER 10000PF 25V X5R 0201 | 0.01uF
31 | 2 | C650,C652 | GRM1555C1H270JA01D | Murata Electronics | CAP CER 27PF 50V C0G/NP0 0402 | 27pF
32 | 2 | C657,C658 |  | Murata Electronics | CAP CER 10UF 25V X7S 0805 | 10uF
33 | 5 | D1,D2,D3,D4,D5 | PESD3V3X1BL,315 | Nexperia USA Inc. | TVS DIODE 3.3V SOD882 | PESD3V3X1BL,315
34 | 1 | D6 | RB751S40T5G | ON Semiconductor | DIODE SCHOTTKY 40V 30MA SOD523 | RB751S40T5G
35 | 1 | D27 | B530C-13-F | Diodes Incorporated | DIODE SCHOTTKY 30V 5A SMC | B530C-13-F
36 | 1 | D28 | SMBJ16CA | Littelfuse Inc | TVS DIODE 16VWM 26VC SMB | SMBJ16CA
37 | 3 | FB18,FB19,FB20 | BLM18PG330SN1D | Murata Electronics North America | FERRITE BEAD 33 OHM 0603 1LN | 33E
38 | 1 | J5 | 77313-818-14LF | Amphenol ICC (FCI) | CONN HEADER VERT 14POS 2.54MM | HEADER 7X2
39 | 1 | J7 | 5000751517 | Molex | CONN RCPT USB2.0 MINI B VERT | MINI-USB TYPE A/B CON
40 | 4 | J11,J18,J19,J20 | U.FL-R-SMT-1(10) | Hirose Electric Co Ltd | CONN U.FL RCPT STR 50 OHM SMD | U.FL
41 | 1 | J12 | 7498111120AR | Würth Elektronik | CONN JACK 1PORT 1000 BASE-T SMD | 7498111120AR
42 | 1 | J22 | PJ-051AH | CUI Inc. | 2.0 mm Center Pin, 5.0 A, Right Angle, Through Hole, Shielded, Dc Power Jack Connector | PJ-051AH
43 | 1 | J23 | M55-7102042R | Harwin | CONN HEADER SMD R/A 20POS 1.27MM | M55-7102042R
44 | 1 | LED2 | LTST-C190TBKT | LITEON | LED Blue Clear 0603 | Blue
45 | 1 | LED4 | LTST-C190KRKT | LITEON | LED Red Clear 0603 | Red
46 | 4 | LED11,LED12,LED13,LED14 | XZCCBDMEDGK161W | SunLED | 2.5X0.7MM LC RGB RIGHT ANGLE SMD | XZCCBDMEDGK161W
47 | 4 | LED19,LED20,LED21,LED22 | LTST-C190KGKT | LITEON | LED Green Clear 2.1V 0603 | GREEN
48 | 1 | L3 | SRP5030TA-1R5M | Bourns Inc. | FIXED IND 1.5UH 6A 25 MOHM SMD | 1.5uH/5A
49 | 1 | L7 | SPM6550T-2R2M-HZ | TDK Corporation | FIX IND 2.2UH 14.2A 10.67MOHM SM | 2.2uH
50 | 1 | L8 | MLC1260-401MLC | Coilcraft | Fixed Inductors Power Inductor 0.4 uH 20 % | 0.44uH
51 | 12 | L9,L11,L12,L13,L20,L21,L22,L23,L24,L25,L26,L51 | FBMH1608HM600-T | Taiyo Yuden | BEAD FERRITE 60 OHM 3A 1608 SMD | 60OHM@100MHZ
52 | 1 | L10 | MDMK4040T1R5MF | Taiyo Yuden | FIXED IND 1.5UH 3.3A 65 MOHM SMD | 1.5uH/3A
53 | 13 | L14,L15,L28,L29,L30,L31,L32,L33,L38,L39,L41,L52,L53 | MPZ1005S121CT000 | TDK Corporation | FERRITE BEAD 120 OHM 0402 1LN | MPZ1005S121C
54 | 2 | L27,L40 | ECS-MPI2520R0-4R7-R | ECS Inc. | FIXED IND 4.7UH 1.4A 288MOHM SMD | 4.7uH/1.4A
55 | 4 | L34,L35,L36,L37 | MLK1005SR10JT000 | TDK | FIXED IND 100NH 100MA 2.2 OHM | 100nH
56 | 2 | L45,L47 | 0402HP-3N3XJLW | Coilcraft | Fixed Inductors 1005 3.3nH Unshld 5% 1.7A 45mOhms | 3.3nH
57 | 1 | L48 | LQH32PN100MN0L | Murata Electronics | FIXED IND 10UH 700MA 380 MOHM | 10uH/0.7A
58 | 1 | L50 | LQH2HPZ6R8MJRL | Murata Electronics | FIXED IND 6.8UH 1A 312 MOHM | 6.8uH/1A
59 | 2 | NR1,NR2 | EXB-38V104JV | Panasonic Electronic Components | RES ARRAY 4 RES 100K OHM 1206 | 100K
60 | 1 | Q1 | CSD17556Q5B | Texas Instruments | MOSFET N-CH 30V 8-VSON | CSD17556Q5B
61 | 2 | Q31,Q32 | MMBT3904LT1G | ON SEMICONDUCTOR | TRANS NPN 40V 0.2A SOT-23 | MMBT3904
62 | 1 | Q34 | CMPT3904 | Central Semiconductor | NPN, 0.2A, 40V | -
63 | 1 | RV1 | 82531040 | Wurth | VARISTOR 8V 150A 1206 | VARISTOR
64 | 53 | R1,R18,R64,R76,R110,R113,R116,R127,R128,R129,R130,R134,R139,R141,R142,R145,R146,R147,R159,R161,R162,R164,R167,R168,R170,R174,R178,R181,R182,R292,R303,R318,R330,R340,R381,R382,R391,R426,R427,R433,R435,R437,R450,R474,R475,R556,R563,R576,R593,R602,R607,R608,R618 | RC0402JR-0710KL | Yageo | RES SMD 10K OHM 5% 1/16W 0402 | 10K
65 | 2 | R4,R22 | RC0402JR-070RL | Yageo | RES SMD 0 OHM JUMPER 1/16W 0402 | 0 OHM
66 | 1 | R6 | RC0402JR-070RL | Yageo | RES SMD 0 OHM JUMPER 1/16W 0402 | 0Ohm
67 | 1 | R61 | RC0402FR-0768KL | Yageo | RES 68K OHM 1/16W 1% 0402 SMD | 68K/1%
68 | 3 | R62,R293,R388 | PFR05S-153-FNH | Delta Electronics/Cyntec | RES SMD 15 KOHM 1% 1/16W 0402 | 15K/1%
69 | 2 | R63,R138 | CRGCQ0402F180K | TE Connectivity Passive Product | CRGCQ 0402 180K 1% | 180K/1%
70 | 1 | R65 | RCL12250000Z0EG | Yageo | RES SMD 0 OHM 2W 2512 WIDE | 0 E
71 | 5 | R67,R71,R112,R149,R231 | RC2512JK-070RL | Yageo | RES SMD 0 OHM JUMPER 1W 2512 | 0 E
72 | 1 | R68 | RMCF0402FT3K01 | Stackpole Electronics Inc | RES 3.01K OHM 1% 1/16W 0402 | 3.01K/1%
73 | 1 | R69 | RMCF0402FT8K45 | Stackpole Electronics Inc | RES 8.45K OHM 1% 1/16W 0402 | 8.45K/1%
74 | 6 | R70,R136,R232,R238,R375,R476 | RC0402FR-0710KL | Yageo | RES 10.0K OHM 1/16W 1% 0402 SMD | 10K/1%
75 | 1 | R72 | RCL12250000Z0EG | Vishay Dale | RES SMD 0 OHM 2W 2512 WIDE | 0 E
76 | 1 | R73 | RC0402FR-07187KL | Yageo | RES 187K OHM 1/16W 1% 0402 SMD | 187K/1%
77 | 1 | R74 | RC0402FR-0724K9L | Yageo | RES SMD 24.9K OHM 1% 1/16W 0402 | 24.9K/1%
78 | 1 | R75 | RC0402FR-07100KL | Yageo | RES SMD 100K OHM 1% 1/16W 0402 | 100K/1%
79 | 1 | R78 | RC0402JR-07100KL | Yageo | RES 100K OHM 1/16W 5% 0402 SMD | 100K
80 | 2 | R87,R621 | RC0402JR-07200KL | Yageo | RES 200K OHM 1/16W 5% 0402 SMD | 200K
81 | 26 | R95,R97,R101,R106,R152,R153,R194,R196,R197,R198,R236,R325,R329,R333,R335,R337,R346,R353,R355,R387,R389,R392,R393,R415,R564,R567 | RC0402JR-071KL | Yageo | RES 1.0K OHM 1/16W 5% 0402 SMD | 1K
82 | 6 | R100,R104,R105,R626,R627,R628 | MCR01MZPJ000 | Rohm Semiconductor | RES SMD 0.0OHM JUMPER 1/16W 0402 | 0E
83 | 8 | R103,R107,R109,R111,R114,R203,R615,R617 | RC0402JR-07330RL | Yageo | RES 330 OHM 1/16W 5% 0402 SMD | 330
84 | 1 | R117 | RC0402FR-07475RL | Yageo | RES 475 OHM 1/16W 1% 0402 SMD | 475/1%
85 | 7 | R124,R175,R183,R328,R331,R336,R338 | RC0402JR-0733RL | Yageo | RES 33 OHM 1/16W 5% 0402 SMD | 33
86 | 7 | R126,R151,R163,R189,R190,R200,R214 | RC0402FR-07240RL | Yageo | RES SMD 240 OHM 1% 1/16W 0402SMD | 240/1%
87 | 1 | R135 | ERJ-2RKF6341X | Panasonic | RES 6.34K OHM 1/16W 1% 0402 SMD | 6.34K/1%
88 | 1 | R137 | ERJ-2RKF7681X | Panasonic | RES 7.68K OHM 1/16W 1% 0402 SMD | 7.68K/1%
89 | 8 | R169,R171,R173,R176,R592,R595,R611,R612 | RC0402JR-070RL | Yageo | RES SMD 0 OHM JUMPER 1/16W 0402 | 0E
90 | 6 | R172,R177,R422,R423,R451,R467 | ERJ-2GE0R00X | Panasonic Electronic Components | RES SMD 0 OHM JUMPER 1/10W 0402 | 0E
91 | 27 | R179,R188,R191,R192,R193,R195,R204,R205,R206,R207,R208,R209,R210,R380,R390,R431,R432,R436,R464,R590,R594,R596,R601,R622,R623,R624,R625 | RC0402JR-074K7L | Yageo | RES 4.7K OHM 1/16W 5% 0402 SMD | 4.7K
92 | 1 | R211 | RC0402JR-07300RL | Yageo | RES SMD 300 OHM 5% 1/16W 0402 | 300
93 | 27 | R216,R217,R218,R219,R220,R221,R222,R223,R224,R225,R226,R227,R228,R441,R442,R452,R453,R454,R455,R456,R457,R458,R459,R460,R461,R462,R463 | RC0402FR-0736RL | Yageo | RES 36.0 OHM 1/16W 1% 0402 SMD | 36/1%
94 | 1 | R235 | RC0402FR-0714K3L | Yageo | RES SMD 14.3K OHM 1% 1/16W 0402 | 14.3K/1%
95 | 2 | R237,R438 | RC0402FR-071RL | Yageo | RES SMD 1 OHM 1% 1/16W 0402 | 1/1%
96 | 7 | R240,R327,R332,R334,R342,R344,R354 | RC0402FR-0749R9L | Yageo | RES 49.9 OHM 1/16W 1% 0402 SMD | 49.9/1%
97 | 1 | R286 | RC0402FR-0714KL | Yageo | RES 14.0K OHM 1/16W 1% 0402 SMD | 14K/1%
98 | 2 | R289,R291 | RC0805FR-072R05L | Yageo | RES 2.05 OHM 1/8W 1% 0805 SMD | 2.05/1%
99 | 1 | R294 | RC0402FR-0717K4L | Yageo | RES SMD 17.4K OHM 1% 1/16W 0402 | 17.4K/1%
100 | 2 | R313,R424 | RC0402FR-07100RL | Yageo | RES 100 OHM 1/16W 1% 0402 SMD | 100/1%
101 | 12 | R317,R324,R356,R366,R405,R408,R417,R418,R421,R440,R443,R610 | RC0402JR-0722RL | Yageo | RES 22 OHM 1/16W 5% 0402 SMD | 22
102 | 2 | R339,R343 | RC0402FR-072K37L | Yageo | RES 2.37K OHM 1/16W 1% 0402 SMD | 2.37K/1%
103 | 1 | R345 | RC0402FR-0737R4L | Yageo | RES 37.4 OHM 1/16W 1% 0402 SMD | 37.4/1%
104 | 7 | R357,R358,R359,R579,R582,R583,R584 | ERJ-2GE0R00X | Panasonic Electronic Components | RES SMD 0 OHM JUMPER 1/10W 0402 | 0ohm
105 | 2 | R406,R407 | RC0402FR-071KL | Yageo | RES 1.00K OHM 1/16W 1% 0402 SMD | 1K/1%
106 | 2 | R419,R420 | RC0201JR-074K7L | Yageo | RES SMD 4.7K OHM 5% 1/20W 0201 | 4.7K
107 | 1 | R448 | RC0402FR-0743KL | Yageo | RES SMD 43K OHM 1% 1/16W 0402 | 43K/1%
108 | 1 | R449 | AC0402FR-0727KL | Yageo | RES SMD 27K OHM 1% 1/16W 0402 | 27K/1%
109 | 1 | R477 | RC0402FR-0720KL | Yageo | RES 20K OHM 1/16W 1% 0402 SMD | 20K/1%
110 | 1 | R545 | ERA-2AEB4532X | Panasonic Electronic Components | RES SMD 45.3KOHM 0.1% 1/16W 0402 | 45K/1%
111 | 1 | R546 | CRT0402-FZ-3002GLF | Bourns | Thin Film Resistors ResThinFilm 0402 30k 1% 63mW TC50 | 30K/1%
112 | 1 | R547 | WSL12064L000FEA | Vishay Dale | RES 0.004 OHM 1% 1/4W 1206 | 0.004
113 | 2 | R548,R552 | RMCF0201FT10K0 | Stackpole Electronics Inc | RES 10K OHM 1% 1/20W 0201 | 10K
114 | 2 | R549,R550 | ERJ-1GNF4322C | Panasonic Electronic Components | RES SMD 43.2K OHM 1% 1/20W 0201 | 43.2K
115 | 1 | R551 | ERJ-1GNF1501C | Panasonic Electronic Components | RES SMD 1.5K OHM 1% 1/20W 0201 | 1.5K
116 | 1 | R553 | ERJ-1GNF6491C | Panasonic Electronic Components | RES SMD 6.49K OHM 1% 1/20W 0201 | 6.49K
117 | 1 | R554 | ERJ-1GNF3651C | Panasonic Electronic Components | RES SMD 3.65K OHM 1% 1/20W 0201 | 3.65K
118 | 1 | R555 | RC0402JR-0710KL | Yageo | RES SMD 10K OHM 5% 1/16W 0402 | 1K
119 | 3 | R557,R558,R559 | RC0402JR-070RL | Yageo | RES SMD 0.0OHM JUMPER 1/16W 0402 | 0E
120 | 1 | R560 | AC0201FR-0747KL | Yageo | RES SMD 47K OHM 1% 1/20W 0201 | 47K
121 | 7 | R568,R570,R571,R572,R573,R574,R575 | ERJ-2GEJ512X | Panasonic Electronic Components | RES SMD 5.1K OHM 5% 1/10W 0402 | 1K
122 | 1 | R569 | ERJ-2GEJ512X | Panasonic Electronic Components | RES SMD 5.1K OHM 5% 1/10W 0402 | 5.1K
123 | 4 | R577,R578,R580,R581 | RC0402JR-0710KL | Yageo | RES SMD 10K OHM 5% 1/16W 0402 | 2K
124 | 1 | R585 | RT0402FRE0736KL | YAGEO | RES SMD 36K OHM 1% 1/16W 0402 | 36K/1%
125 | 1 | R586 | RC0402FR-0739K2L | Yageo | RES 39.2K OHM 1% 1/16W 0402 | 39.2K/1%
126 | 2 | R587,R588 | RK73H1ETTP1500F | KOA Speer Electronics, Inc. | RES 150 OHM 1% 1/10W 0402 | 150E
127 | 1 | R609 | RC0402FR-074K99L | Yageo | RES SMD 4.99K OHM 1% 1/16W 0402 | 4.99K 1%
128 | 1 | R613 | CRCW0402100KFKED | Vishay Dale | RES SMD 100K OHM 1% 1/16W 0402 | 100K
129 | 1 | SW1 | TL3305BF160QG | E-Switch | SWITCH TACTILE SPST-NO 50MA 12V | Tact Switch
130 | 1 | S1 | 1825027-2 | TE Connectivity | SWITCH TACTILE SPST-NO 0.05A 12V | 1825027-2
131 | 1 | U1 | CNF7130-1000BG772-G | Cavium | Cavium OCTEON Fusion CNF7130 | CNF7130-1000BG772-G
132 | 1 | U3 | AD9363BBCZ | Analog Device | RF Transceiver | AD9363ABCZ
133 | 1 | U4 | TPS54519RTET | Texas Instruments | IC REG BUCK ADJUSTABLE 5A 16WQFN | TPS54519
134 | 1 | U5 | SN74LVC1G08DCKR | Texas Instruments | IC GATE AND 1CH 2-INP SC-70-5 | SN74LVC1G08DCKR
135 | 5 | U6,U18,U32,U33,U57 | SN74LVC1G17QDCKRQ1 | Texas Instruments | IC BUF NON-INVERT 5.5V SC70-5 | 74LVC1G17SE-7
136 | 1 | U7 | TPS53353DQPT | Texas Instruments | IC REG BUCK ADJUSTABLE 20A 22SON | TPS53353DQPT
137 | 1 | U8 | LM73606RNPR | Texas Instruments | IC REG BUCK ADJUSTABLE 6A 30WQFN | LM73606RNPR
138 | 1 | U10 | MCP1316MT-29KE/OT | Microchip Technology | IC SUPERVISOR 2.9V SOT23-5 | MCP1316
139 | 5 | U11,U15,U23,U30,U35 | IS43TR16256AL-15HBLI | ISSI | DRAM 4G, 1.35V, 1333Mhz DDR3L SDAM | DDR3_128/256Mb*16
140 | 1 | U12 | 625L3C050M00000 | CTS-Frequency Controls | XTAL OSC XO 50.0000MHZ CMOS SMD | Oscillator 50Mhz
141 | 1 | U13 | PI6C557-03BLE | Diodes Incorporated | IC CLOCK GENERATOR 16TSSOP | PI6C557-03BLE/5V41235PGGI8
142 | 1 | U14 | TPS54319RTET | Texas Instruments | IC REG BUCK ADJUSTABLE 3A 16WQFN | TPS54319
143 | 3 | U16,U17,U34 | 74LVC1G08SE-7 | Diodes Incorporated | IC GATE AND 1CH 2-INP SOT353 | 74LVC1G08SE-7
144 | 1 | U19 | AT24C64D-XHM-B | Microchip Technology | IC EEPROM 64KBIT 1MHZ 8TSSOP | AT24C64D-XHM-B
145 | 1 | U20 | TCA9554DBQR | TI | Interface - I/O Expanders Remote 8-bit I2C SMBus I/O Expander | TCA9554DBQR
146 | 1 | U22 | 74ALVT16373DGG,118 | Nexperia USA Inc. | IC TRANSP LATCH 16BIT D 48TSSOP | 74ALVT16373DGG
147 | 1 | U24 | DMC2038LVT-7 | Diodes Incorporated | MOSFET N/P-CH 20V TSOT26 | DMC2038LVT-7
148 | 1 | U25 | TXB0101DBVR | TI | 1 bit bidirectional voltage level translator,SOT23-6 | TXB0101DBVR
149 | 1 | U26 | FT230XQ-R | FTDI, Future Technology Devices International Ltd | IC USB SERIAL BASIC UART 16QFN | FT230XQ
150 | 1 | U27 | SN74CBTD3861PWR | TI | IC 10-BIT FET BUS SW 24-TSSOP | SN74CBTD3861PWR
151 | 1 | U28 | TMP464AIRGTR | Texas Instruments | Temperature Sensor | TMP464AIRGTR
152 | 1 | U29 | EMMC16G-M525-B53 | Kingston | 16GB eMMC NAND with JEDEC/MMC standard version 4.51-compliant | EMMC16G-M525-B53
153 | 1 | U31 | ADUM1201ARZ-RL7 | Analog Devices Inc. | DGTL ISO 2.5KV GEN PURP 8SOIC | ADUM1201ARZ/ISO7221
154 | 1 | U38 | U7769LF | Rakon | IC OCXO mercury ultra low noise 30.72MHZ | OCXO-30.72Mhz/U7769LF
155 | 5 | U39,U40,U43,U66,U67 | TCM1-63AX+ | Mini Circuits | Surface mount RF Transdormer 50ohm 10~6 GHZ | TCM1-63AX+
156 | 1 | U42 | TPS51200DRCR | Texas Instruments | IC REG CONV DDR 1OUT 10VSON | TPS51200DRCT
157 | 1 | U44 | DAC8571IDGKR | TI | IC DAC 16BIT I2C V-OUT LP 8VSSOP | DAC8571IDGKR
158 | 4 | U63,U69,U83,U245 | AP3418KTR-G1 | Diodes Incorporated | IC REG BUCK ADJ 1.5A SOT23-5 | AP3418KTR-G1
159 | 1 | U64 | MT28EW01GABA1HJS-0SIT TR | Micron Technology Inc. | IC FLASH 1G PARALLEL 56TSOP | JS28F512M29EWH
160 | 1 | U65 | ADP1755ACPZ-R7 | Analog Device | IC REG LIN POS ADJ 1.2A 16LFCSP | ADP1755ACPZ-R7
161 | 2 | U70,U71 | GVA-63+ | Mini-Circuits | RF Amplifier ML AMPL / SURF MT / RoHS | GVA-63+
162 | 1 | U242 | LP3943ISQ/NOPB | Texas Instruments | IC LED DRIVER PS DIM 25MA 24WQFN | LP3943
163 | 1 | U243 | 88E6341_QFN88 | Marvell | ETHERNET SWITCH | 88E6341_QFN88
164 | 1 | U246 | LM25066APSQE/NOPB | Texas Instruments | IC CTLR PM HOTSWAP 24WQFN | LM25066
165 | 1 | U250 | CAT24C64WI-GT3 | ON Semiconductor | IC EEPROM 64KBIT 400KHZ 8SOIC | CAT24C64WI-GT3
166 | 2 | U252,U253 | TPD4E05U06 | Texas Instruments | TVS DIODE 5.5VWM 14VC 10USON | TPD4E05U06
167 | 1 | U254 | PCA9306DCTR | Texas Instruments | IC TRNSLTR BIDIRECTIONAL SM8 | PCA9306DCTR
168 | 1 | Y2 | 8Z-12.000MAHQ-T | TXC CORPORATION | CRYSTAL 12.0000MHZ 10PF SMD | 12MHZ
169 | 2 | Y3,Y4 | ABM10AIG-25.000MHZ-4Z-T3 | Abracon LLC | CRYSTAL 25MHZ 10PF SMD | 25MHz
170 | 1 | Z1 | 5.0SMDJ15A | Littelfuse Inc. | TVS DIODE 15V 24.4V DO214AB | DIODE ZENER_0

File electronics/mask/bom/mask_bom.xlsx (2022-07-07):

Item | Quantity | Reference | Part Number | Manufacturer | Description | Value
1 | 2 | C1,C6 | APXG200ARA181MH70G | United Chemi-Con | CAP ALUM POLY 180UF 20% 20V SMD | 180uF
2 | 8 | C2,C3,C16,C17,C19,C25,C28,C31 | C1005X7R1E104K050BB | TDK Corporation | CAP CER 0.1UF 25V 10% X7R 0402 | 0.1UF
3 | 7 | C7,C10,C41,C45,C47,C53,C56 | CC0603KRX7R7BB105 | Yageo | CAP CER 1UF 16V 10% X7R 0603 | 1uF
4 | 28 | C8,C9,C12,C13,C14,C15,C18,C20,C21,C22,C23,C24,C26,C27,C29,C32,C33,C34,C35,C36,C38,C39,C40,C43,C44,C50,C51,C54 | CC0402KRX7R8BB104 | Yageo | CAP CER 0.1UF 25V X7R 0402 | 0.1uF
5 | 6 | C11,C2B1,C2B2,C42,C48,C49 | TMK316B7106KL-TD | Taiyo Yuden | CAP CER 10UF 25V 10% X7R 1206 | 10uF
6 | 1 | C37 | CC0402JRNPO9BN100 | Yageo | CAP CER 10PF 50V 5% NPO 0402 | 10pF
7 | 1 | C46 | UMK212B7105KG-T | Taiyo Yuden | CAP CER 1UF 50V X7R 0805 | 1uF
8 | 1 | C52 | C2012X7R1A475K125AC | TDK Corporation | CAP CER 4.7UF 10V 10% X7R 0805 | 4.7UF
9 | 1 | C55 | GRM32EC80J107ME20L | Murata Electronics North America | CAP CER 100UF 6.3V X6S 1210 | 100uF
10 | 2 | C57,C58 | CC0402KRX7R8BB102 | Yageo | CAP CER 1000PF 25V X7R 0402 | 1000pF
11 | 1 | D1 | RB751S40T5G | ON Semiconductor | DIODE SCHOTTKY 40V 30MA SOD523 | RB751S40T5G
12 | 2 | D2,D4 | B530C-13-F | Diodes Incorporated | DIODE SCHOTTKY 30V 5A SMC | B530C-13-F
13 | 1 | D3 | SMBJ16CA | Littelfuse Inc | TVS DIODE 16VWM 26VC SMB | SMBJ16CA
14 | 10 | FB1,FB2,FB3,FB4,FB5,FB6,FB7,FB8,FB9,FB10 | BLM18PG121SN1D | Murata Electronics North America | FERRITE CHIP 120 OHM 2000MA 0603 | 120E / 2A
15 | 1 | JTB1 | S2B-XH-A(LF)(SN) | Molex | CONN HEADER R/A 2POS 2.5MM | S2B-XH-A(LF)(SN)
16 | 2 | J1,J3 | 1775838-2 | TE Connectivity AMP Connectors | CONN PCI EXP MINI FEMALE 52POS | 1775838-2
17 | 1 | J2 | FX23-60P-0.5SV15 | Hirose Connector | CONN HDR 60POS SMD GOLD | FX23_60PIN_CONN
18 | 1 | J4 | FX23-60S-0.5SV | Hirose Connector | CONN RCPT 60POS SMD GOLD | FX23_60PIN_CONN
19 | 3 | LED1,LED2,LED3 | LTST-C193TBKT-5A | Lite-On Inc | LED BLUE CLEAR CHIP SMD | LED
20 | 1 | L1 | 7447779002 | Wurth Electronics Inc | FIXED IND 2.2UH 4.2A 20 MOHM SMD | 2.2uH
21 | 3 | Q1,Q2,Q3 | 2N7002-7-F | Diodes Inc | MOSFET N-CH 60V 115MA SOT23-3 | 2N7002L
22 | 32 | R1,R2,R3,R4,R6,R7,R8,R9,R16,R19,R24,R25,R29,R30,R33,R35,R36,R38,R42,R47,R54,R56,R58,R62,R64,R70,R73,R74,R76,R78,R81,R85 | ERJ-2GE0R00X | Panasonic Electronic Components | RES 0.0 OHM 1/10W JUMP 0402 SMD | 0 Ohm
23 | 38 | R5,R15,R17,R21,R22,R26,R27,R28,R31,R32,R34,R37,R39,R40,R41,R43,R44,R45,R46,R48,R49,R50,R52,R53,R55,R57,R65,R66,R67,R68,R69,R71,R72,R77,R79,R83,R87,R88 | ERJ-2GEJ103X | Panasonic Electronic Components | RES 10K OHM 1/10W 5% 0402 SMD | 10K
24 | 3 | R12,R13,R14 | CRG0805F220R | TE Connectivity Passive Product | RES SMD 220 OHM 1% 1/8W 0805 | 220
25 | 3 | R18,R80,R86 | RC0603JR-070RL | Yageo | RES SMD 0 OHM JUMPER 1/10W 0603 | 0E
26 | 1 | R20 | RC0402FR-0742K2L | Yageo | RES SMD 42.2K OHM 1% 1/16W 0402 | 42.2K/1%
27 | 1 | R23 | RC0402FR-0747KL | Yageo | RES SMD 47K OHM 1% 1/16W 0402 | 47K
28 | 1 | R51 | ERA-2AEB123X | Panasonic Electronic Components | RES SMD 12K OHM 0.1% 1/16W 0402 | 12K
29 | 1 | R59 | RC0402FR-07240KL | Yageo | RES SMD 240K OHM 1% 1/16W 0402 | 240K
30 | 1 | R60 | RC0402FR-07100KL | Yageo | RES SMD 100K OHM 1% 1/16W 0402 | 100K
31 | 1 | R61 | ERJ-2GEJ104X | Panasonic Electronic Components | RES 100K OHM 1/10W 5% 0402 SMD | 100K
32 | 1 | R63 | RMCF0402FT41K2 | Stackpole Electronics Inc | RES SMD 41.2K OHM 1% 1/16W 0402 | 41.2K
33 | 1 | R75 | ERA-2AEB104X | Panasonic Electronic Components | RES SMD 100K OHM 0.1% 1/16W 0402 | 100K
34 | 1 | R82 | RC0402FR-0734K8L | Yageo | RES SMD 34.8K OHM 1% 1/16W 0402 | 34.8K
35 | 1 | R84 | RC0402FR-0728KL | Yageo | RES SMD 28K OHM 1% 1/16W 0402 | 28K
36 | 1 | SW1 | TS01AQE | E-Switch | SWITCH SLIDE SPDT 3A 120V | TS01AQE
37 | 2 | U1,U9 | SLG7NT408V | Dialog Semiconductor | Ultra-small 7.8 mO, 4 A | SLG7NT408V
38 | 2 | U2,U8 | AP7165-SPG-13 | Diodes Incorporated | IC REG LDO ADJ 0.6A 8SOP | AP7165
39 | 1 | U3 | ADM6316DZ26ARJZ-R7 | Analog Devices Inc | IC SUPERVISOR WATCHDOG SOT23-5 | ADM6316DZ26ARJZ-R7
40 | 1 | U4 | TCA9406DCTR | Texas Instruments | Voltage Level Translator Bidirectional 1 Circuit 2 Channel 24Mbps SM8 | TCA9406DCTR
41 | 1 | U5 | SX1509BIULTRT | Semtech | IC GPIO EXPANDER I2C 16CH 28QFN | SX1509B
42 | 1 | U6 | SN74LVC1T45DRLR | Texas Instruments | IC BUS TRANSCVR TRI-ST SOT-563 | SN74LVC1T45DRLR
43 | 1 | U7 | LT8640IUDC#TRPBF | Linear Technology | IC REG BUCK ADJ 5A 20QFN | LT8640EUDC

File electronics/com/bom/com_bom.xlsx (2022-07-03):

Revised: Friday, February 25, 2022
Revision: ?
Bill Of Materials March 10,2022 12:40:31 | Page1
Item | Quantity | Reference | Part Number | Manufacturer | Description | Value | Assembly | No_Mount | PCB Footprint
______________________________________________
1 | 1 | CN1 | 112A-TAAR-R03 | Attend Technology Inc | MICROSD Connector | 112A-TAAR-R03_ATTEND |  | - | microsd_attend_new
2 | 1 | CR1L1 | BAT54C-7-F | Diodes Incorporated | DIODE ARRAY SCHOTTKY 30V SOT23-3 | BAT54C |  |  | SOT23
3 | 14 | C4,C5,C6,C7,C27,C31,C34,C37,C39,C42,C91,C92,C134,C151 | GRM033R61E104ME14D | Murata Electronics North America | CAP CER 0.1UF 25V X5R 0201 | 0.1UFX |  | - | SM_2_CAP-RES_0201_20H
4 | 63 | C1A2,C1B3,C1B7,C2C1,C2N2,C2N3,C2C3,C2N4,C2N6,C2N7,C2C7,C2N8,C2N9,C3N1,C3N2,C3N4,C3N6,C3L6,C3N7,C3N8,C3N9,C4M3,C4L5,C2N10,C2N11,C2B11,C2N12,C2C12,C2B12,C2N13,C2M13,C2M14,C2L15,C2N16,C2M17,C2M18,C2N22,C2N23,C2N25,C2N26,C2B35,C2B37,C2N38,C2N39,C2N40,C2N41,C2N43,C3N11,C3M11,C3N12,C3L12,C3N13,C3L15,C3N16,C3N20,C3N23,C3M23,C3N24,C3N25,C3M28,C3M30,C3M33,C4P23 | GRM155C81E105KE11D | Murata Electronics North America | CAP CER 1UF 25V X6S 0402 | 1UF |  | - | SMC0402A
5 | 18 | C1A3,C2B8,C2B9,C3L4,C4M2,C4M7,C2L14,C2B39,C2B51,C2B52,C3L14,C3L18,C3L19,C3L20,C3L21,C3L22,C3L23,C4P19 | C3216X7R1E106K160AB | TDK Corporation | CAP CER 10UF 25V X7R 1206 | 10UF |  | - | SMC1206
6 | 4 | C1A4,C1A5,C2A14,C2A15 | CL31X226KAHN3NE | Samsung Electro-Mechanics America, Inc | CAP CER 22UF 25V X6S 1206 | 22UF |  | - | SMC1206
7 | 17 | C1B1,C2B2,C2B3,C2B4,C2B5,C2B6,C4P5,C2B13,C2B19,C2B20,C2B40,C2B49,C3A13,C324,C3A27,C3A28,C4P25 | C3216X6S1A476M160AC | TDK Corporation | CAP CER 47UF 10V X6S 1206 | 47UF |  | - | SMC1206
8 | 21 | C1B2,C3M3,C3L5,C4L4,C4L6,C2A10,C2B14,C2B15,C2L16,C2N44,C2N45,C2N46,C2N47,C3A10,C3M12,C3M13,C3L17,C3M26,C3M32,C4P10,C4P18 | GRM188C81C106MA73D | Murata Electronics North America | CAP CER 10UF 16V X6S 0603 | 10UF |  | - | SMC0603
9 | 14 | C1B4,C2B1,C2M12,C2B34,C2B41,C2B42,C2B43,C2B45,C2B46,C2B47,C2B48,C2B50,C3M19,C3M180 | GRM31CD80J107ME39L | Murata Electronics North America | CAP CER 100UF 6.3V X6T 1206 | 100UF |  | - | SMC1206
10 | 3 | C1D2,C2B23,C3B17 | GRM155C80J106ME11D | Murata Electronics North America | CAP CER 10UF 6.3V X6S 0402 | 10UF |  | - | SMC0402A
11 | 32 | C1N3,C2N5,C3L9,C2A11,C2A12,C2N14,C2N15,C2B18,C2M20,C2B29,C2B30,C2B31,C2N32,C2B32,C2N33,C2N34,C2N37,C3N14,C3B15,C3A24,C3A26,C3M29,C3N30,C3N31,C4P21,C1918,C1981,C1982,C1999,C2000,C2037,C2038 | 04023C104KAT2A | AVX Corporation | CAP CER 0.1UF 25V 10% X7R 0402 | 0.1uF |  | - | SMC0402A
12 | 8 | C1N7,C1N8,C1N9,C2A1,C2A3,C1N10,C4662,C4749 | C1005X7R1E104K050BB | TDK Corporation | CAP CER 0.1UF 25V 10% X7R 0402 | 0.1uF |  |  | SMC0402A
13 | 2 | C18,C129 | CL05A105MP5NNNC | Samsung Electro-Mechanics | CAP CER 1UF 10V X5R 0402 | 1UFX_16V |  | - | SMC0402A
14 | 2 | C2A9,C2A13 | 592D337X0010R2T20H | VISHAY | CAP TANT 330UF 10V 20% 2824 | 330UF |  | - | SMC7260_80TALL
15 | 1 | C3L7 | 04025A120JAT2A | AVX | CAP CER 12PF 50V NP0 0402 | 12PF |  | NM | SMC0402A
16 | 3 | C2B7,C2B10,C2B16 | CL21B106KOQNNNE | Samsung Electro-Mechanics America, Inc | CAP CER 10UF 16V X7R 0805 | 10UF |  | - | C0805
17 | 8 | C2C2,C2B36,C3M14,C3M15,C3M18,C3M20,C3M21,C3M181 | C2012X7S1A226M125AC | TDK Corporation | CAP CER 22UF 10V X7S 0805 | 22UF |  | - | SMC0805
18 | 1 | C2C8 | 6TPE330MAP | Panasonic Electronic Components | CAP TANT POLY 330UF 6.3V 2917 | 330UF |  | - | CAPMP7343X190N
19 | 11 | C2M9,C2M22,C2M24,C3B14,C3B18,C3B20,C3B23,C3B25,C3B26,C3B34,C3B35 | GRM155R71C104KA88J | TDK Corporation | CAP CER 0.1UF 25V 10% X7R 0402 | 0.1UF |  |  | C0201
20 | 1 | C2P3 | 6TPE330MAP | Panasonic Electronic Components | CAP TANT POLY 330UF 6.3V 2917 | 330UF |  | - | SMC7343_75TALL
21 | 6 | C3C1,C2A16,C2A17,C2N31,C3A22,C3B33 | 04023C104KAT2A | AVX Corporation | CAP CER 0.1UF 25V 10% X7R 0402 | 0.1UF |  | NM | SMC0402A
22 | 3 | C3M1,C3M5,C3M179 | AMK212BC6476MG-T | Taiyo Yuden | CAP CER 47UF 4V X6S 0805 | 47UF |  | - | C0805
23 | 2 | C3M6,C3M7 | C1005X7S1A105K050BC | TDK Corporation | CAP CER 1UF 10V X7S 0402 | 1UF |  | NM | SMC0402A
24 | 1 | C3M8 | GRM188R61C225KE15E | MURATA | CAP CER 2.2UF 16V X5R 0603 | 2.2UF |  |  | SMC0603
25 | 2 | C3M9,C2B17 | GRM188R61C225KE15E | MURATA | CAP CER 2.2UF 16V X5R 0603 | 2.2UF |  | NM | SMC0603
26 | 2 | C3N3,C3A12 | C2012X7S1A226M125AC | TDK Corporation | CAP CER 22UF 10V X7S 0805 | 22UF |  | - | C0805
27 | 4 | C69,C70,C139,C140 | C1005X7R1E104K050BB | TDK Corporation | CAP CER 0.1UF 25V 10% X7R 0402 | 0.1uF |  | - | C0201
28 | 13 | C164,C165,C181,C202,C203,C224,C243,C244,C264,C279,C280,C301,C325 | GRM21BB31A106KE18L | Murata Electronics North America | Multilayer Ceramic Capacitors MLCC - SMD/SMT 10UF 10V 10% 0805 | 10uF |  | - | C0805
29 | 86 | C167,C168,C169,C170,C171,C172,C175,C176,C177,C180,C182,C183,C184,C185,C186,C188,C189,C191,C208,C209,C210,C211,C212,C213,C220,C221,C222,C223,C228,C230,C231,C232,C233,C234,C235,C236,C248,C249,C250,C252,C253,C256,C257,C258,C259,C262,C265,C266,C267,C268,C269,C270,C271,C281,C282,C283,C284,C285,C286,C292,C293,C294,C295,C296,C297,C308,C309,C310,C311,C313,C314,C315,C342,C343,C344,C345,C346,C347,C348,C349,C350,C351,C352,C2158,C2159,C4746 | GRM155B31E104KA87D | Murata Electronics North America | 0402 100nF ±10% 25V -B | 0.1uF |  | - | SMC0402A
30 | 6 | C2B21,C3B12,C3M25,C3N28,C3N29,C4P24 | GRM188C80G226MEA0D | Murata Electronics North America | CAP CER 22UF 4V X6S 0603 | 22UF |  | - | SMC0603
31 | 4 | C2N1,C2M16,C3A23,C3A25 | CBR04C180F5GAC | Kemet | CAP CER 18PF 50V NP0 0402 | 18PF |  | - | SMC0402A
32 | 2 | C4M6,C4M10 | C2012X7R1A106M125AC | TDK Corporation | CAP CER 10UF 10V X7R 0805 | 10UF |  |  | SMC0805
33 | 4 | C4M9,C1L11,C3M10,C4A10 | C1005X7S1A105K050BC | TDK Corporation | CAP CER 1UF 10V X7S 0402 | 1UF |  |  | SMC0402A
34 | 1 | C2B22 | LMK107BJ106MALTD | TAIYO | CAP CER 10UF 10V X5R 0603 | 10UF |  | NM | SMC0603
35 | 4 | C2M19,C2B24,C2B25,C3M31 | GRM155R71H103KA88D | Murata Electronics North America | CAP CER 10000PF 50V X7R 0402 | 0.01UF |  | - | SMC0402A
36 | 2 | C2B55,C2B56 | C3216X7R1E106K160AB | TDK | CAP CER 10UF 25V X7R 1206 | 10UF |  |  | SMC1206
37 | 1 | C2M10 | UMK212B7105KG-T | Taiyo Yuden | CAP CER 1UF 50V X7R 0805 | 1UF |  |  | C0805
38 | 2 | C2M11,C2M23 | CC0402JRNPO9BN100 | Yageo | CAP CER 10PF 50V 5% NPO 0402 | 10PF |  |  | C0402
39 | 3 | C2M15,C3B16,C3B21 | C0402C103K5RAC | KEMET | CAP CER 10000PF 50V X7R 0402 | 0.01UF |  |  | C0402
40 | 1 | C2M21 | ECJ-1VB1H393K | PANASONIC | CAP CER 0.039UF 50V X7R 0603 | 0.039UF |  |  | SMC0603
41 | 2 | C2N17,C2N19 | C1005X6S0G475M050BC | TDK Corporation | CAP CER 4.7UF 4V X6S 0402 | 4.7UF |  | - | SMC0402A
42 | 6 | C2N18,C2N27,C2N28,C2N36,C3N18,C3N27 | C1005X7S1A225K050BC | TDK Corporation | CAP CER 2.2UF 10V X7S 0402 | 2.2UF |  | - | SMC0402A
43 | 1 | C2N24 | JMK105B7474KVHF | Taiyo Yuden | CAP CER 0.47UF 6.3V X7R 0402 | 0.47UF |  | - | SMC0402A
44 | 1 | C3A14 | GRM31CD80J107ME39L | Murata Electronics North America | CAP CER 100UF 6.3V X6T 1206 | 100UF |  | NM | SMC1206
45 | 2 | C3B22,C3B32 | CC0402JRNPO9BN100 | Yageo | CAP CER 10PF 50V 5% NPO 0402 | 10PF |  | - | SMC0402A
46 | 1 | C3B36 | C1005X7R1E104K050BB | TDK Corporation | CAP CER 0.1UF 25V 10% X7R 0402 | 0.1UF |  |  | C0201
47 | 1 | C3L10 | GRM155R71H102KA01D | Murata Electronics North America | CAP CER 1000PF 50V X7R 0402 | 1000PF |  | - | SMC0402A
48 | 2 | C3M17,C3M24 | LMK107BJ106MALTD | TAIYO | CAP CER 10UF 10V X5R 0603 | 10UF |  |  | SMC0603
49 | 1 | C3M22 | CL21B106KOQNNNE | Samsung Electro-Mechanics America, Inc | CAP CER 10UF 16V X7R 0805 | 10UF |  | - | SMC0805
50 | 1 | C3M27 | AMK212BC6476MG-T | Taiyo Yuden | CAP CER 47UF 4V X6S 0805 | 47UF |  | - | SMC0805
51 | 1 | C3N21 | GRM155C81E105KE11D | Murata Electronics North America | CAP CER 1UF 25V X6S 0402 | 1UF |  | NM | SMC0402A
52 | 1 | C3N26 | CGA3E1X7S1C225M080AC | TDK Corporation | CAP CER 2.2UF 16V X7S 0603 | 2.2UF |  | - | SMC0603
53 | 1 | C4A11 | C1005X7S1A105K050BC | TDK Corporation | CAP CER 1UF 10V X7S 0402 | 1UF |  | - | SMC0402A
54 | 4 | C1833,C2153,C2154,C2155 | GRM155R71H103KA88D | Murata Electronics North America | CAP CER 10000PF 50V X7R 0402 | 10NF |  | - | SMC0402A
55 | 5 | C2034,C2036,C2152,C2156,C2157 | C1005X7R1E104K050BB | TDK Corporation | CAP CER 0.1UF 25V 10% X7R 0402 | 0.1uF |  | - | SMC0402A
56 | 1 | C2039 | CL05B681KB5NNNC | Samsung Electro-Mechanics America, Inc | CAP CER 680PF 50V X7R 0402 | 680pF |  | NM | SMC0402A
57 | 1 | C2040 | CC0603KRX7R7BB105 | Yageo | CAP CER 1UF 16V 10% X7R 0603 | 1uF |  | - | SMC0603
58 | 1 | C2130 | C3225X7R1C156M250AB | TDK Corporation | CAP CER 15UF 16V X7R 1210 | 15uF |  |  | cc1210
59 | 2 | C2131,C2132 | GRM155R60J156ME05D | Murata Electronics | CAP CER 15UF 6.3V X5R 0402 | 15uF |  |  | cc0402
60 | 2 | C4671,C4672 | GCM155R72A102KA37D | Murata Electronics North America | 1000pF ±10% 50V Ceramic Capacitor X7R 0402 (1005 Metric) | 1000PF | Mount |  | SMC0402A
61 | 1 | C4745 | 04023C104KAT2A | TDK Corporation | CAP CER 0.1UF 25V X7R 0402 | 0.1uF | Mount |  | SMC0402A
62 | 1 | C4747 | C1005X7R1E104K050BB | TDK Corporation | CAP CER 0.1UF 25V 10% X7R 0402 | 0.1uF |  | - | cc0402
63 | 2 | C4750,C4751 | GRM033R61E104ME14D | Murata Electronics North America | CAP CER 0.1UF 25V X5R 0201 | 0.1uF | Mount |  | C0201
64 | 1 | C4752 | SCCQ12E105PRB |  |  | SCCQ12E105PRB |  |  | cap_thr_0p6D
65 | 1 | D1 | D5V0L2B3T-7 | Diodes Inc | TVS DIODE 5VWM 14VC SOT523 | D5V0L2B3T |  | - | SOT_P3_1_70x0_85_0_90mm
66 | 1 | D10089 | PMEG3010ER,115 | NXP Semiconductors | DIODE SCHOTTKY 30V 1A SOD123W | PMEG3010ER,115 |  | - | SODFL3517X110N_NXP_AEE
67 | 3 | D10113,D10115,D10148 | LTST-C190KGKT | Lite-On Inc | LED GREEN CLEAR 0603 SMD | LED |  | - | LED_LTST-C190
68 | 1 | D10136 | PMEG3002AEB,115 | NXP Semiconductors | DIODE SCHOTTKY 30V 0.2A SOD523 | PMEG3002AEB |  | - | SODFL1608X65N_AEE
69 | 2 | D10147,D10149 | PMEG3002AEB,115 | NXP Semiconductors | DIODE SCHOTTKY 30V 0.2A SOD523 | PMEG3002AEB |  | NM | SODFL1608X65N_AEE
70 | 1 | J20 | FX23-120P-0.5SV15 | Hirose | CONN HDR 120POS SMD GOLD | FX23-120P_COM |  |  | CON_120P_44_00X9_20_13_15MM
71 | 1 | J3321 | HTST-110-01-L-DV | Samtec | CONN HEADER 20POS UNSHD VERT T/H | eJTAG Header |  | - | CONN_20P_33_02X9_27_10_16MM
72 | 10 | L1D1,L3M1,L3M2,L3M3,L3M5,L3M6,L3M7,L4M1,L4L1,L4M2 | IHLP1616ABERR47M11 | VISHAY | FIXED IND 470NH 6A 21 MOHM SMD | 0.47UH |  | - | SMI16_16AB
73 | 1 | L2A1 | 744311220 | WURTH ELEKTRONIK | FIXED IND 2.2UH 9A 11.4 MOHM SMD | 2.2UH |  | - | SMI29_28
74 | 2 | L2B1,L2B2 | HM72B-061R0LFTR13 | BI TECHNOLOGIES | FIXED IND 1UH 10.3A 10 MOHM SMD | 1.0UH |  | - | SML28_28
75 | 2 | L2L1,L3M4 | IHLP1616ABER1R0M11 | VISHAY | FIXED IND 1UH 4.2A 47 MOHM SMD | 1UH |  | - | SMI16_16AB
76 | 6 | MH1,MH2,MH3,MH4,MH5,MH6 |  |  |  | Mounting_Hole |  | - | MTG370_800
77 | 2 | NR4,NR5 | EXB-38V104JV | Panasonic Electronic Components | RES ARRAY 4 RES 100K OHM 1206 | 100K |  | - | CA_3_20x1_60_0_50mm
78 | 2 | Q1D1,Q3A1 | FDMA507PZ | FAIRCHILD SEMICONDUCTOR | MOSFET P-CH 20V 6-MICROFET | FDMA507PZ |  | - | MICROFET6_2X2_P65MM_EP
79 | 2 | Q2B1,Q3B1 | MMBT3904LT1G | ON SEMICONDUCTOR | TRANS NPN 40V 0.2A SOT23 | MMBT3904 |  | - | SOT23
80 | 1 | Q2N1 | FDG6301N | FAIRCHILD SEMICONDUCTOR | MOSFET 2N-CH 25V 0.22A SC70-6 | FDG6301N |  | - | SC70_6P
81 | 2 | Q40,Q41 | MMBT3904LT1G | ON SEMICONDUCTOR |  | MMBT3904 |  |  | SOT23
82 | 3 | Q135,Q137,Q138 | DMG1012T-7 | Diodes Incorporated | MOSFET N-CH 20V 630MA SOT-523 | DMG1012T-7 |  | - | SOT523_3P_1_70X0_85_0_90MM
83 | 1 | R1A1 | CRCW04022K20JNED | VISHAY-DALE |  | 2.2K |  |  | SMC0402A
84 | 2 | R1A2,R1A14 | CRCW04022K20JNED | VISHAY-DALE |  | 2.2K |  | NM | SMC0402A
85 | 7 | R1A3,R1A4,R1A5,R1A7,R1A8,R1A11,R1A12 | RK73H1ETTP1002F | KOA SPEER |  | 10K |  | NM | SMC0402A
86 | 2 | R1A6,R1A15 | RK73H1ETTP1002F | KOA SPEER |  | 10K |  |  | SMC0402A
87 | 1 | R1A9 | RK73H1ETTP1002F | KOA SPEER |  | 10K |  | - | SMC0402A
88 | 1 | R1B2 | RC0402FR-0766K5L | YAGEO | RES 66.5K 1% 1/16W 0402 | 66.5K |  | - | SMC0402A
89 | 4 | R1B8,R1B14,R1B23,R1B24 | RC0402FR-071K8L | YAGEO | RES 1.8K 1% 1/16W 0402 | 1.8K |  | - | SMC0402A
90 | 1 | R1L1 | ERJ-2GEJ102X | Panasonic Electronic Components | RES 1K OHM 1/10W 5% 0402 SMD | 1K |  |  | SMC0402A
91 | 1 | R1L2 | RK73Z1ETTP | KOA SPEER |  | 0 |  |  | SMC0402A
92 | 1 | R1L3 | RK73Z1ETTP | KOA SPEER |  | 0 |  |  | SMR0402A
93 | 3 | R1N4,R1N17,R2M44 | CRCW04023K30JNED | VISHAY-DALE | RES 3.3K 5% 1/16W 0402 | 3.3K |  | - | SMC0402A
94 | 6 | R10,R11,R12,R20,R21,R22 | RC0201FR-0710KL | Yageo | RES SMD 10K OHM 1% 1/20W 0201 | 10K |  | - | SM_2_CAP-RES_0201_20H
95 | 3 | R2A1,R2A3,R2A5 | RK73B1ETTP103J | KOA SPEER |  | 10K |  |  | SMC0402A
96 | 3 | R2B1,R4M6,R3L16 | RC0402FR-0760K4L | YAGEO | RES SMD 60.4K OHM 1% 1/16W 0402 | 60.4K |  | - | SMC0402A
97 | 5 | R2B2,R3M1,R4L2,R4P6,R2L12 | RK73H1ETTP5362F | KOA SPEER | RES 53.6K 1% 1/16W 0402 | 53.6K |  | - | SMC0402A
98 | 4 | R2B4,R3L4,R3L14,R3B15 | ERJ-2GEJ102X | Panasonic Electronic Components | RES 1K OHM 1/10W 5% 0402 SMD | 1K |  | NM | SMC0402A
99 | 11 | R2B6,R2B8,R3B3,R3A5,R2B12,R2B43,R2B44,R2B45,R3C19,R4P11,R10557 | ERJ-2RKF2002X | Panasonic Electronic Components | RES SMD 20K OHM 1% 1/10W 0402 | 20K |  | - | SMC0402A
100 | 3 | R2C9,R2C12,R3A19 | ERJ-2GEJ330X | Panasonic Electronic Components | RES SMD 33 OHM 5% 1/10W 0402 | 33 |  | - | SMC0402A
101 | 3 | R2N5,R2B22,R2B31 | RK73H1ETTP1000F | KOA SPEER | RES 100 1% 1/16W 0402 | 100 |  | - | SMC0402A
102 | 9 | R2C1,R3C1,R2B33,R2B34,R3C14,R3B16,R3A20,R3N25,R3N26 | RC0402FR-074K7L | YAGEO | RES SMD 4.7K OHM 1% 1/16W 0402 | 4.7K |  | - | SMC0402A
103 | 22 | R2N1,R2N2,R1B19,R1P28,R1P29,R1P30,R2A17,R2N20,R2N21,R2B38,R2B39,R3L15,R3C20,R4M14,R10373,R10388,R10709,R10803,R10809,R11024,R11144,R11154 | RK73B1ETTP103J | KOA SPEER | RES 10K 5% 1/16W 0402 | 10K |  | - | SMC0402A
104 | 7 | R3B4,R3C5,R3L7,R2B10,R3B12,R3B13,R10378 | ERJ-2GEJ102X | Panasonic Electronic Components | RES 1K OHM 1/10W 5% 0402 SMD | 1K |  | - | SMC0402A
105 | 1 | R3B5 | RK73B1ETTP105J | KOA SPEER | RES 1M 5% 1/16W 0402 | 1M |  | - | SMC0402A
106 | 2 | R3B8,R3B14 | RK73H1ETTP45R3F | KOA SPEER | RES 45.3 1% 1/16W 0402 | 45.3 |  | - | SMC0402A
107 | 8 | R3L6,R3B9,R4M9,R2B15,R2B19,R3M11,R3N24,R4M12 | RK73Z1ETTP | KOA Speer Electronics, Inc. | RES 0 OHM JUMPER 0402 | 0 |  | - | SMC0402A
108 | 1 | R3C8 | ERJ-2RKF2201X | Panasonic Electronic Components | RES SMD 2.2K OHM 1% 1/10W 0402 | 2.2K |  | - | SMC0402A
109 | 2 | R55,R11486 | RC0402JR-070RL | Yageo | RES SMD 0 OHM JUMPER 1/16W 0402 | 0 OHM |  | - | SMC0402A
110 | 6 | R2A19,R2A20,R2A21,R2A22,R2A23,R2A25 | RC0402JR-070RL | YAGEO |  | 0 |  | - | SMR0402A
111 | 1 | R3L8 | ERJ-2RKF3602X | Panasonic Electronic Components | RES SMD 36K OHM 1% 1/10W 0402 | 36K |  | - | SMC0402A
112 | 1 | R3L9 | ERJ2RKF2003X | PANASONIC | RES 200K 1% 1/16W 0402 | 200K |  | - | SMC0402A
113 | 9 | R3M4,R3M7,R2M36,R2M38,R2M39,R2M41,R4M20,R4M21,R4M24 | RC0402FR-07100KL | Yageo | RES SMD 100K OHM 1% 1/16W 0402 | 100K |  | - | SMC0402A
114 | 4 | R2N7,R3N6,R3N16,R3N20 | ERJ-2RKF49R9X | Panasonic Electronic Components | RES 49.9 OHM 1/10W 1% 0402 SMD | 49.9 |  | - | SMC0402A
115 | 4 | R3N7,R3N8,R2M35,R3N14 | RK73H1ETTP4020F | KOA SPEER | RES 0402 1% 1/16W 0402 | 402 |  | - | SMC0402A
116 | 2 | R36,R39 | RC0201JR-074K7L | Yageo | RES SMD 4.7K OHM 5% 1/20W 0201 | 4.7K |  | - | SM_2_CAP-RES_0201_20H
117 | 1 | R1A10 | RC0402FR-074K7L | YAGEO |  | 4.7K |  | NM | SMC0402A
118 | 1 | R1B29 | RC0402FR-071K8L | YAGEO |  | 1.8K |  |  | SMC0402A
119 | 3 | R1B30,R1B31,R1B32 | RC0402FR-071K8L | YAGEO |  | 1.8K |  |  | SMR0402A
120 | 10 | R2N6,R2A14,R2A15,R2A16,R10375,R11021,R11022,R11156,R11157,R11231 | ERJ-2GE0R00X | Panasonic Electronic Components | RES SMD 0.0OHM JUMPER 1/10W 0402 | 0 |  | - | SMC0402A
121 | 15 | R3M5,R1P17,R2N18,R2N19,R2B32,R3M10,R3B11,R3B17,R3C18,R4M18,R4M19,R4M22,R4M23,R10552,R11023 | RK73B1ETTP103J | KOA SPEER | RES 10K 5% 1/16W 0402 | 10K |  | NM | SMC0402A
122 | 1 | R185 | MCR01MZPJ103 |  |  | 0R DNF |  | - | SM_2_CAP-RES_0201_20H
123 | 9 | R2A13,R3A17,R10603,R10605,R10606,R10607,R10608,R10609,R10610 | ERJ-2GE0R00X | Panasonic Electronic Components | RES SMD 0.0OHM JUMPER 1/10W 0402 | 0 |  | NM | SMC0402A
124 | 1 | R2A18 | RC0402JR-070RL | YAGEO |  | 0 |  | - | SMC0402A
125 | 2 | R2A24,R2N26 | RC0402JR-070RL | YAGEO |  | 0 |  | NM | SMR0402A
126 | 3 | R2B25,R2B27,R2B29 | CRCW040273R2FKED | Vishay Dale | RES SMD 73.2 OHM 1% 1/16W 0402 | 73.2 |  | - | SMC0402A
127 | 1 | R2B36 | RK73Z1ETTP | KOA SPEER |  | 0 |  | NM | SMC0402A
128 | 4 | R2C25,R2C26,R10782,R10788 | ERJ-2GEJ104X | Panasonic Electronic Components | RES 100K OHM 1/10W 5% 0402 SMD | 100K |  | - | SMC0402A
129 | 14 | R2M24,R2M28,R2M30,R2M42,R2M46,R2M47,R2M48,R2M50,R2M52,R2M54,R2M55,R2M56,R2M57,R2M58 | RK73B1ETTP103J | KOA SPEER |  | 10K |  |  | SMR0402A
130 | 4 | R2M25,R2M49,R2M51,R2M53 | RK73B1ETTP103J | KOA SPEER | RES 10K 5% 1/16W 0402 | 10K |  | - | R0402
131 | 1 | R2M26 | RC0402JR-070RL | YAGEO | RES SMD 0 OHM JUMPER 1/16W 0402 | 0 |  |  | SMR0402A
132 | 1 | R2M27 | RC0402FR-07127RL | Yageo | RES SMD 0 OHM JUMPER 1/16W 0402 | 127E |  |  | SMR0402A
133 | 1 | R2M29 | RK73B1ETTP105J | KOA SPEER | RES 10K 5% 1/16W 0402 | 1M |  | NM | R0402
134 | 1 | R2M31 | RK73H1ETTP1500F | KOA SPEER | RES 150 1% 1/16W 0402 | 150 |  | NM | SMC0402A
135 | 1 | R2M32 | RC0402FR-0747R5L | YAGEO | RES 47.5 1% 1/16W 0402 | 47.5 |  | - | SMC0402A
136 | 1 | R2M33 | RK73H1ETTP1500F | KOA SPEER | RES 150 1% 1/16W 0402 | 150 |  | - | SMC0402A
137 | 1 | R2M34 | RK73H1ETTP4021F | KOA SPEER | RES 4.02K 1% 1/16W 0402 | 4.02K |  | - | SMC0402A
138 | 1 | R2M37 | RK73B1ETTP103J | KOA SPEER | RES 10K OHM 5% 1/10W 0402 | 10K |  |  | SMR0402A
139 | 2 | R2M40,R2M45 | RK73H1ETTP1241F | KOA SPEER | RES 1.24K 1% 1/16W 0402 | 1.24K |  | - | SMC0402A
140 | 2 | R2M43,R3A18 | RK73B1ETTP106J | KOA SPEER | RES 10M 5% 1/16W 0402 | 10M |  | - | SMC0402A
141 | 1 | R2M59 | CRCW04024K99FKED | VISHAY-DALE | RES SMD 4.99K OHM 1% 1/16W 0402 | 4.99K |  |  | SMR0402A
142 | 1 | R2M60 | RC0402JR-070RL | YAGEO | RES SMD 0 OHM JUMPER 1/16W 0402 | 0 |  | DNP | SMR0402A
143 | 2 | R2N13,R3N27 | RK73H1ETTP90R9F | KOA SPEER | RES 90.9 1% 1/16W 0402 | 90.9 |  | - | SMC0402A
144 | 1 | R2M61 | RK73B1ETTP103J | KOA SPEER |  | 10K |  | DNP | SMR0402A
145 | 1 | R2N12 | RK73H1ETTP1620F | KOA SPEER | RES 162 1% 1/16W 0402 | 162 |  | - | SMC0402A
146 | 1 | R2N14 | RK73H1ETTP29R4F | KOA SPEER | RES 29.4 1% 1/16W 0402 | 29.4 |  | - | SMC0402A
147 | 4 | R2N15,R2N16,R3N28,R3N29 | RK73H1ETTP44R2F | KOA SPEER | RES 44.2 1% 1/16W 0402 | 44.2 |  | NM | SMC0402A
148 | 2 | R2N24,R2N25 | RC0402JR-070RL | YAGEO | RES SMD 0.0OHM JUMPER 1/10W 0402 | 0 |  |  | SMC0402A
149 | 4 | R211,R11439,R11440,R11441 | ERJ-2GEJ102X | Panasonic Electronic Components | RES 1K OHM 1/10W 5% 0402 SMD | 1K |  | - | SMR0402A
150 | 16 | R267,R269,R296,R297,R346,R352,R421,R422,R476,R480,R546,R547,R614,R615,R640,R641 | GRM033R61E104ME14D | Murata Electronics North America | CAP CER 0.1UF 25V X5R 0201 | 0.1uF |  | - | SM_2_CAP-RES_0201_20H
151 | 16 | R268,R270,R298,R299,R350,R351,R423,R424,R481,R482,R542,R548,R616,R617,R639,R642 | ERA-2AEB203X | Panasonic Electronic Components | RES SMD 20K OHM 0.1% 1/16W 0402 | 20.0k |  | - | SMC0402A
152 | 1 | R3B10 | RK73Z1ETTP | KOA Speer Electronics, Inc. | RES 0 OHM JUMPER 0402 | 0 |  | NM | SMC0402A
153 | 4 | R3B19,R3B20,R3B21,R3B22 | RK73Z1ETTP | KOA Speer Electronics, Inc. | RES 0 OHM JUMPER 0402 | 0 |  |  | SMC0402A
154 | 1 | R3B23 | RK73Z1ETTP | KOA SPEER | RES 0 OHM JUMPER 0402 | 0 |  |  | SMC0402A
155 | 2 | R3C10,R3C16 | CRCW040220R0FKED | VISHAY-DALE | RES 20 1% 1/16W 0402 | 20 |  | - | SMC0402A
156 | 1 | R3C12 | CRCW040216R9FKEA | VISHAY | RES 16.9 1% 1/16W 0402 | 16.9 |  | - | SMC0402A
157 | 1 | R3C17 | CRCW04022K20JNED | VISHAY-DALE | RES 2.2K 5% 1/16W 0402 | 2.2K |  | NM | SMC0402A
158 | 1 | R3L11 | RK73B1ETTP204J | KOA SPEER | RES 200K 5% 1/16W 0402 | 200K |  | - | SMC0402A
159 | 1 | R3L12 | RC0402FR-0773K2L | Yageo | RES SMD 73.2K OHM 1% 1/16W 0402 | 73.2K |  | - | SMC0402A
160 | 1 | R3L13 | RK73H1ETTP1203F | KOA SPEER | RES 120K 1% 1/16W 0402 | 120K |  | - | SMC0402A
161 | 1 | R3N15 | CRCW040249R9FKED | VISHAY-DALE | RES 49.9 OHM 1/10W 1% 0402 SMD | 49.9 |  |  | SMC0402A
162 | 1 | R3N30 | RK73H1ETTP23R2F | KOA SPEER | RES 23.2 1% 1/16W 0402 | 23.2 |  | - | SMC0402A
163 | 4 | R301,R375,R562,R647 | MCR01MZPF2400 | Rohm Semiconductor | 0402 240O ±1% 0.063W ±100ppm | 240 |  | - | SMC0402A
164 | 1 | R384 | MCR01MZPJ000 | Rohm Semiconductor | RES SMD 0 OHM JUMPER 1/16W 0402 | 0 |  | - | SMC0402A
165 | 2 | R4A12,R4A13 | CRCW04021K00FKED | VISHAY-DALE |  | 1K |  | NM | SMC0402A
166 | 2 | R4A14,R4A15 | RC0402FR-079K1L | Yageo | RES SMD 9.1K OHM 1% 1/16W 0402 | 9.1K |  | - | SMC0402A
167 | 1 | R4M17 | RC0402FR-07100KL | Yageo | RES SMD 100K OHM 1% 1/16W 0402 | 100K |  | NM | SMC0402A
168 | 4 | R618,R619,R622,R623 | RC0402JR-070RL | Panasonic Electronic Components | RES SMD 0 OHM JUMPER 1/10W 0402 | 0 |  |  | R0402
169 | 8 | R620,R624,R625,R626,R11491,R11495,R11504,R11507 | RC0402JR-0710KL | Yageo | RES SMD 10K OHM 5% 1/16W 0402 | 10K |  |  | R0402
170 | 2 | R627,R11490 | RC0402JR-070RL | Panasonic Electronic Components | RES SMD 0 OHM JUMPER 1/10W 0402 | 0 |  |  | EIA-0402
171 | 1 | R658 | MCR01MZPF2200 | Rohm Semiconductor | RES SMD 220 OHM 1% 1/16W 0402 | 220 |  |  | SMC0402A
172 | 4 | R1352,R1353,R1354,R1359 | CRCW0402100KFKED | Vishay Dale | RES SMD 100K OHM 1% 1/16W 0402 | 100K | DNP |  | SMC0402A
173 | 5 | R1355,R1356,R1357,R1358,R11275 | RC0402JR-0710KL | Yageo | RES SMD 10K OHM 5% 1/16W 0402 | 10K |  |  | SMC0402A
174 | 2 | R1360,R1361 | RC0402JR-070RL | Yageo | RES SMD 0.0OHM JUMPER 1/16W 0402 | 0E |  |  | SMC0402A
175 | 9 | R1750,R1751,R1752,R1753,R11256,R11374,R11375,R11377,R11378 | ERJ-2GE0R00X | Panasonic Electronic Components | RES SMD 0.0OHM JUMPER 1/16W 0402 | 0E |  |  | SMC0402A
176 | 4 | R10550,R10551,R11165,R11166 | ERJ-2GEJ220X | Panasonic Electronic Components | RES SMD 22 OHM 5% 1/10W 0402 | 22 |  | - | SMC0402A
177 | 4 | R10762,R10763,R10764,R10765 | ERJ-2RKF22R0X | Panasonic Electronic Components | RES SMD 22 OHM 1% 1/10W 0402 | 22 |  | - | SMC0402A
178 | 2 | R10781,R10787 | RMCF0805JT120R | Stackpole Electronics Inc | RES 120 OHM 1/8W 5% 0805 | 120 |  | - | SMC0805
179 | 6 | R10805,R11155,R11160,R11161,R11221,R11223 | ERJ-2GEJ104X | Panasonic Electronic Components | RES 100K OHM 1/10W 5% 0402 SMD | 100K |  | NM | SMC0402A
180 | 1 | R10806 | RC0603FR-07100RL | Yageo | RES SMD 100 OHM 1% 1/10W 0603 | 100E |  | NM | SMC0603
181 | 1 | R10811 | ERJ-2RKF2002X | Panasonic Electronic Components | RES SMD 20K OHM 1% 1/10W 0402 | 20K |  | NM | SMC0402A
182 | 2 | R11130,R11131 | RC0402FR-07127RL | Yageo | RES SMD 127 OHM 1% 1/16W 0402 | 127E |  | - | SMC0402A
183 | 2 | R11132,R11133 | ERJ-2RKF10R0X | Panasonic Electronic Components | RES SMD 10 OHM 1% 1/10W 0402 | 10E |  |  | SMC0402A
184 | 1 | R11145 | HCJ2512ZT0R00 | Stackpole Electronics Inc | RES SMD 0.0 OHM JUMPER 2512 | 0E |  | - | rc2512
185 | 11 | R11162,R11163,R11222,R11224,R11262,R11263,R11264,R11265,R11266,R11267,R11274 | ERJ-2GEJ103X | Panasonic Electronic Components | RES 10K OHM 1/10W 5% 0402 SMD | 10K |  | - | SMC0402A
186 | 25 | R11232,R11233,R11234,R11235,R11236,R11237,R11238,R11239,R11240,R11241,R11242,R11243,R11244,R11245,R11246,R11247,R11248,R11249,R11250,R11251,R11252,R11253,R11254,R11255,R11257 | RC0201FR-0736RL | Yageo | RES SMD 36 OHM 1% 1/20W 0201 | 36E |  | - | SM_2_CAP-RES_0201_20H
187 | 2 | R11259,R11260 | ERJ-2RKF22R0X |  | RES SMD 22 OHM 1% 1/10W 0402 | 22 |  |  | SMC0402A
188 | 1 | R11261 | RC0201FR-0710KL | Yageo | RES SMD 10K OHM 1% 1/20W 0201 | 10K |  | NM | SM_2_CAP-RES_0201_20H
189 | 4 | R11276,R11277,R11278,R11279 | ERJ-2RKF49R9X | Panasonic Electronic Components | RES 49.9 OHM 1/10W 1% 0402 SMD | 49.9 |  |  | R0402
190 | 1 | R11280 | RC0402JR-070RL | Yageo | RES SMD 0 OHM JUMPER 1/16W 0402 | 0E |  | - | R0402
191 | 1 | R11376 | RC0402JR-0710KL | Yageo | RES SMD 10K OHM 5% 1/16W 0402 | 10K |  | DNP | SMC0402A
192 | 2 | R11379,R11380 | RC0402FR-0734RL | Yageo | RES SMD 34 OHM 1% 1/16W 0402 | 34E |  | - | SMR0402A
193 | 1 | R11381 | RMCF0805JT120R | Stackpole Electronics Inc | RES 120 OHM 1/8W 5% 0805 | 120 |  | - | rc0805
194 | 1 | R11382 | ERJ-2GEJ104X | Panasonic Electronic Components | RES 100K OHM 1/10W 5% 0402 SMD | 100K |  | - | rc0402
195 | 2 | R11487,R11501 | ERJ-2GE0R00X | Panasonic Electronic Components | RES 0.0 OHM 1/10W JUMP 0402 SMD | 0 |  | - | rc0402
196 | 3 | R11492,R11497,R11499 | RC0402JR-0710KL | Yageo | RES SMD 10K OHM 5% 1/16W 0402 | 10K | DNP |  | R0402
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

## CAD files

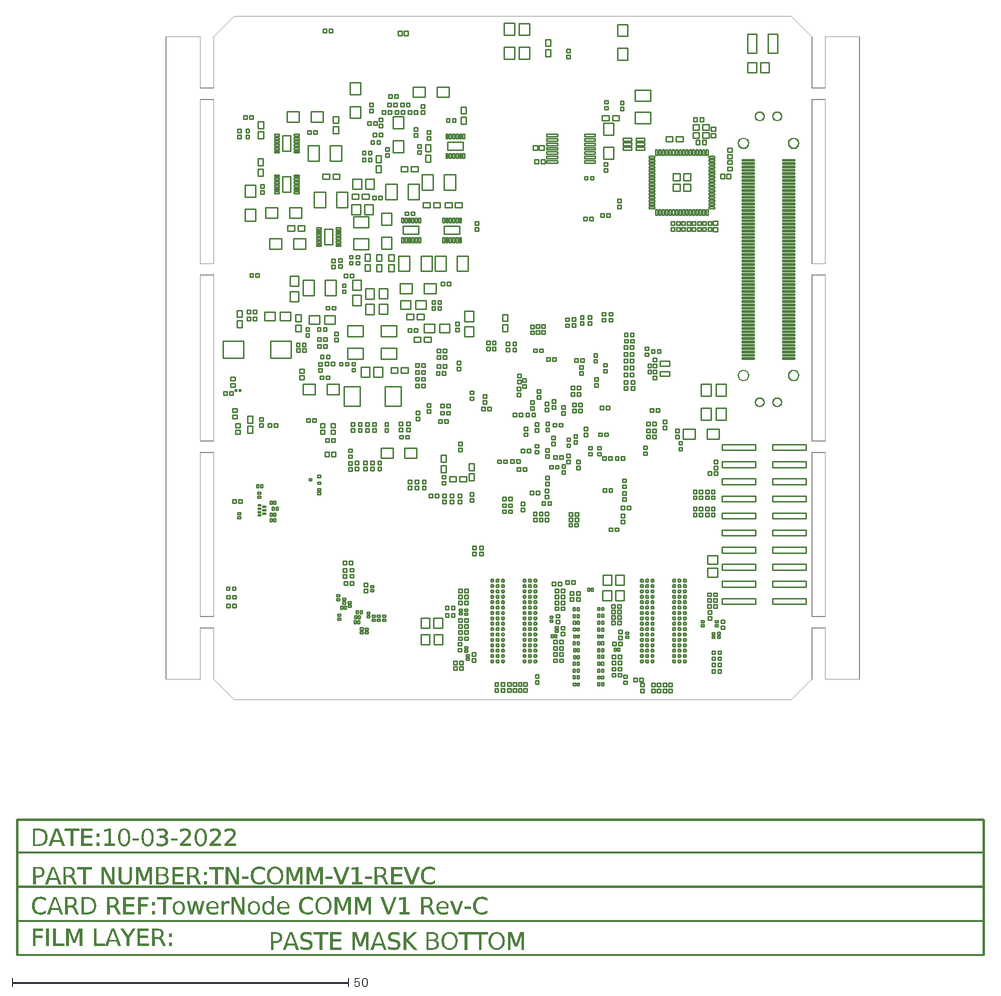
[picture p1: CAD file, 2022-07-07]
electronics/com/stencil/com_pmb.dxf
PASTE MASK BOTTOM
FILM LAYER:
CARD REF:TowerNode COMM V1 Rev-C
DATE:10-03-2022
PART NUMBER:TN-COMM-V1-REVC

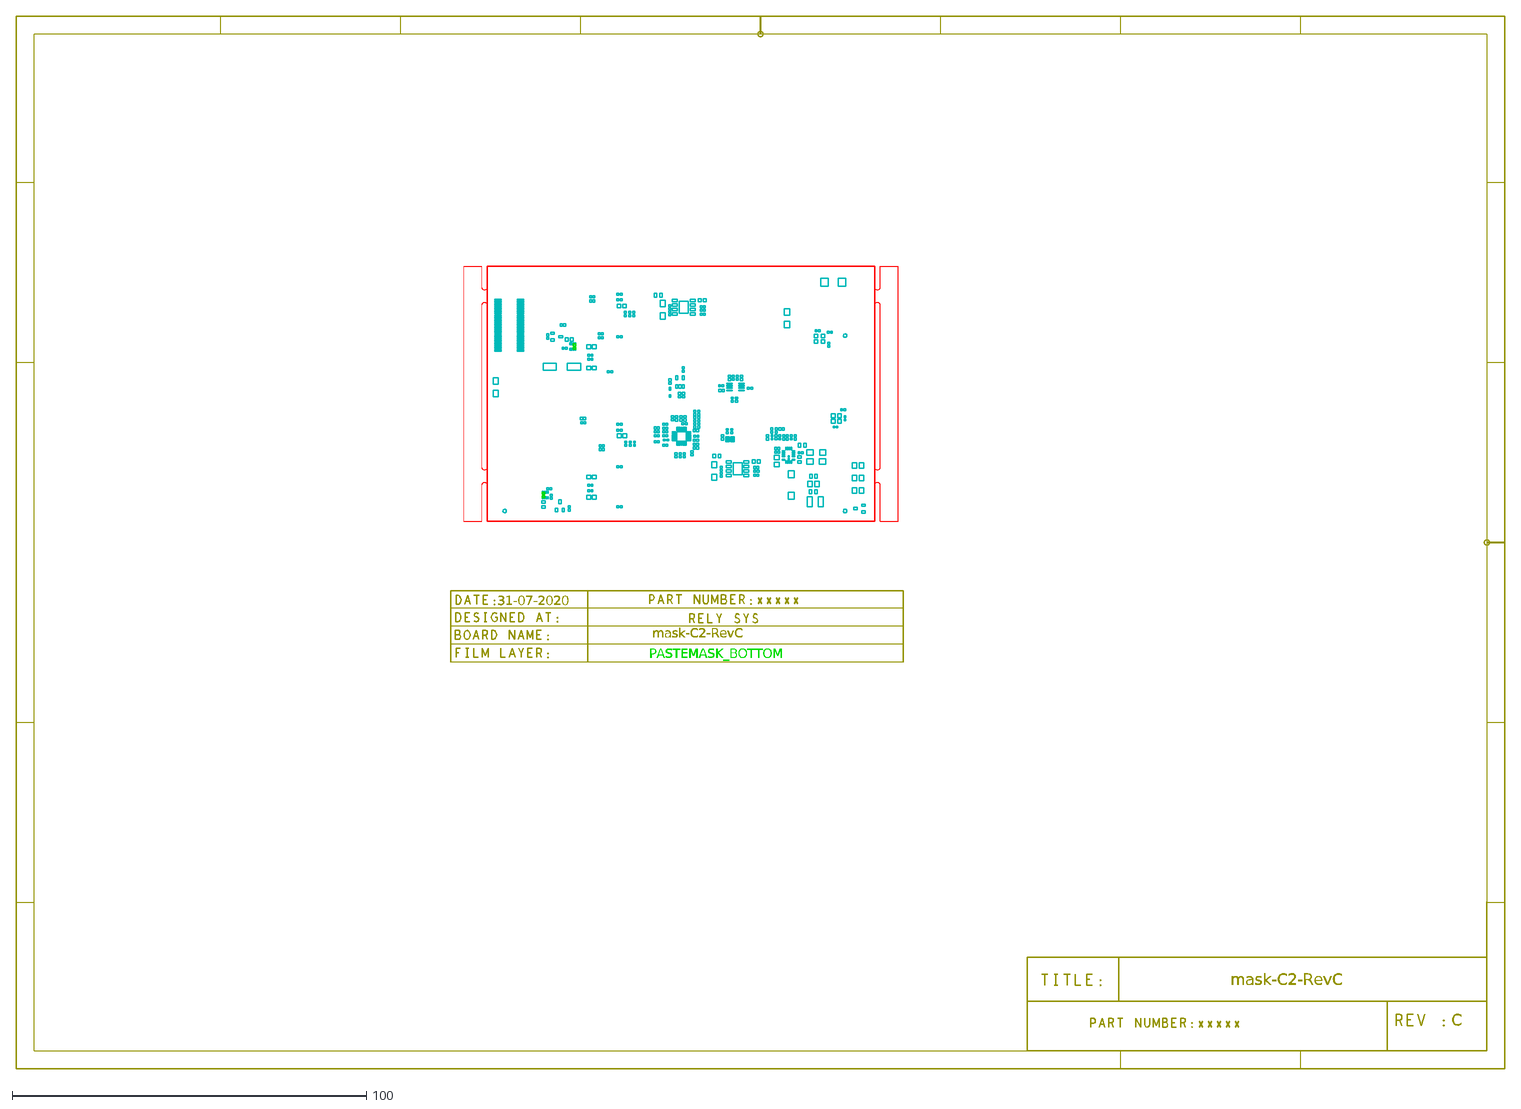
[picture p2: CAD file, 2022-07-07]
electronics/mask/stencil/mask_stencil_pmb.dxf
C
31-07-2020
mask-C2-RevC
PASTEMASK_BOTTOM

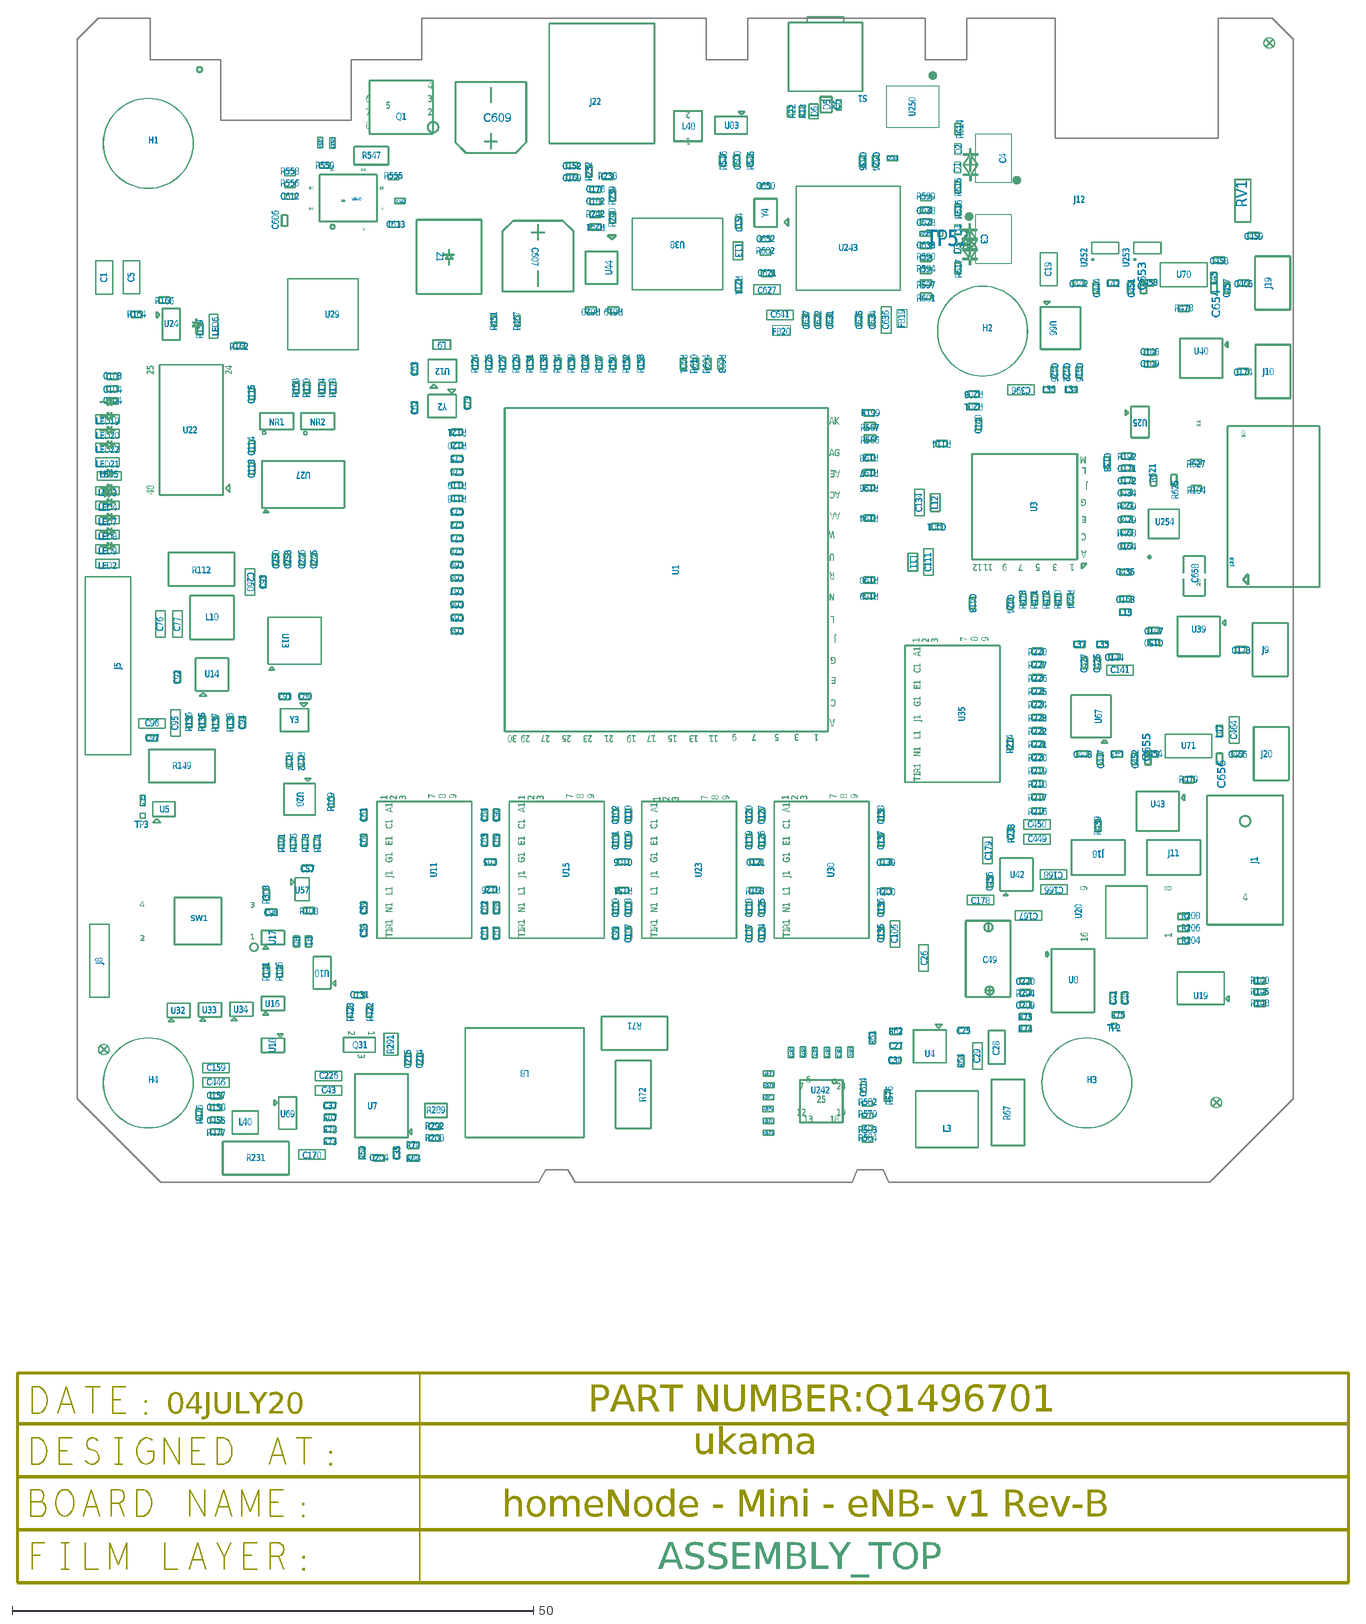
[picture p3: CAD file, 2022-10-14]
electronics/mini_trx/assembly/mini_trx_ast.dxf
1
2
4
3
SW1
RV1
U71
U70
20
13
7
25
24
19
12
8
U246
J22
J12
10
11
J23
L3
H4
H1
H2
H3
U254
U38
C656
C655
C654
C653
R61
C30
R62
C27
C25
R64
R621
R625
R617
R615
R208
R206
R204
R567
R566
C606
R241
R620
R619
R120
R121
R119
C74
C75
R118
C72
C73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

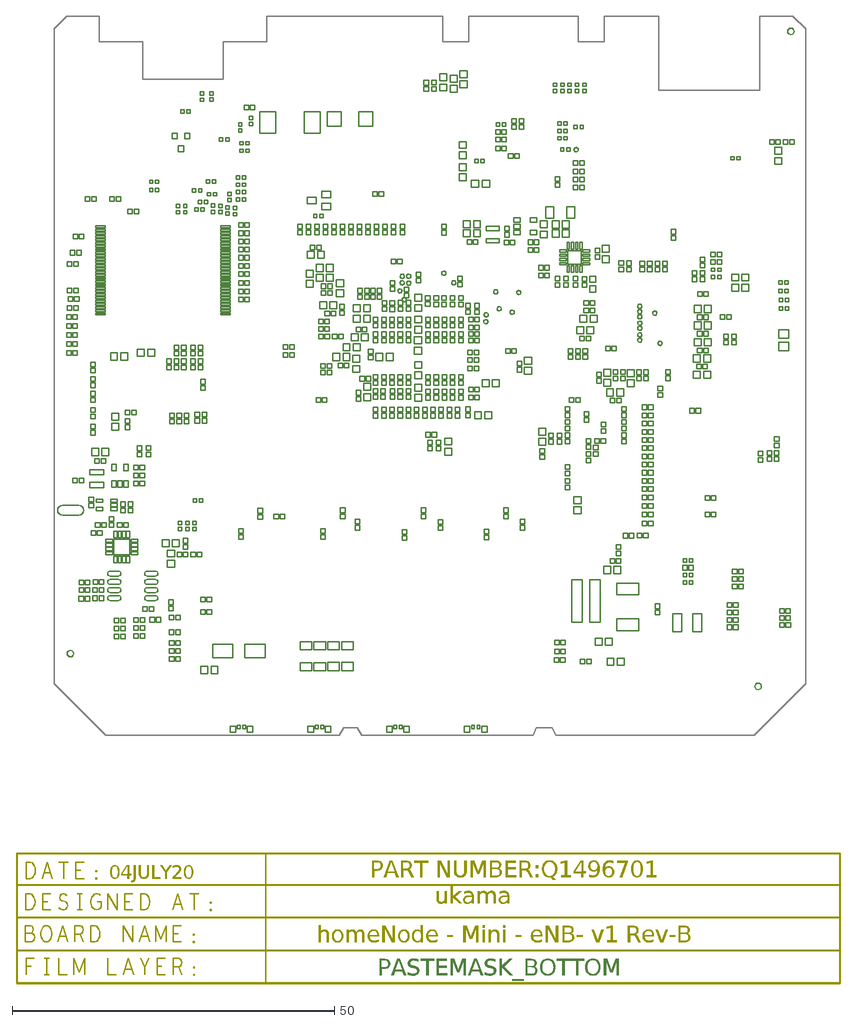
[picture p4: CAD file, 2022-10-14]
electronics/mini_trx/stencil/mini_trx_pmb.dxf
PART NUMBER:Q1496701
ukama
04JULY20
homeNode - Mini - eNB- v1 Rev-B
PASTEMASK_BOTTOM

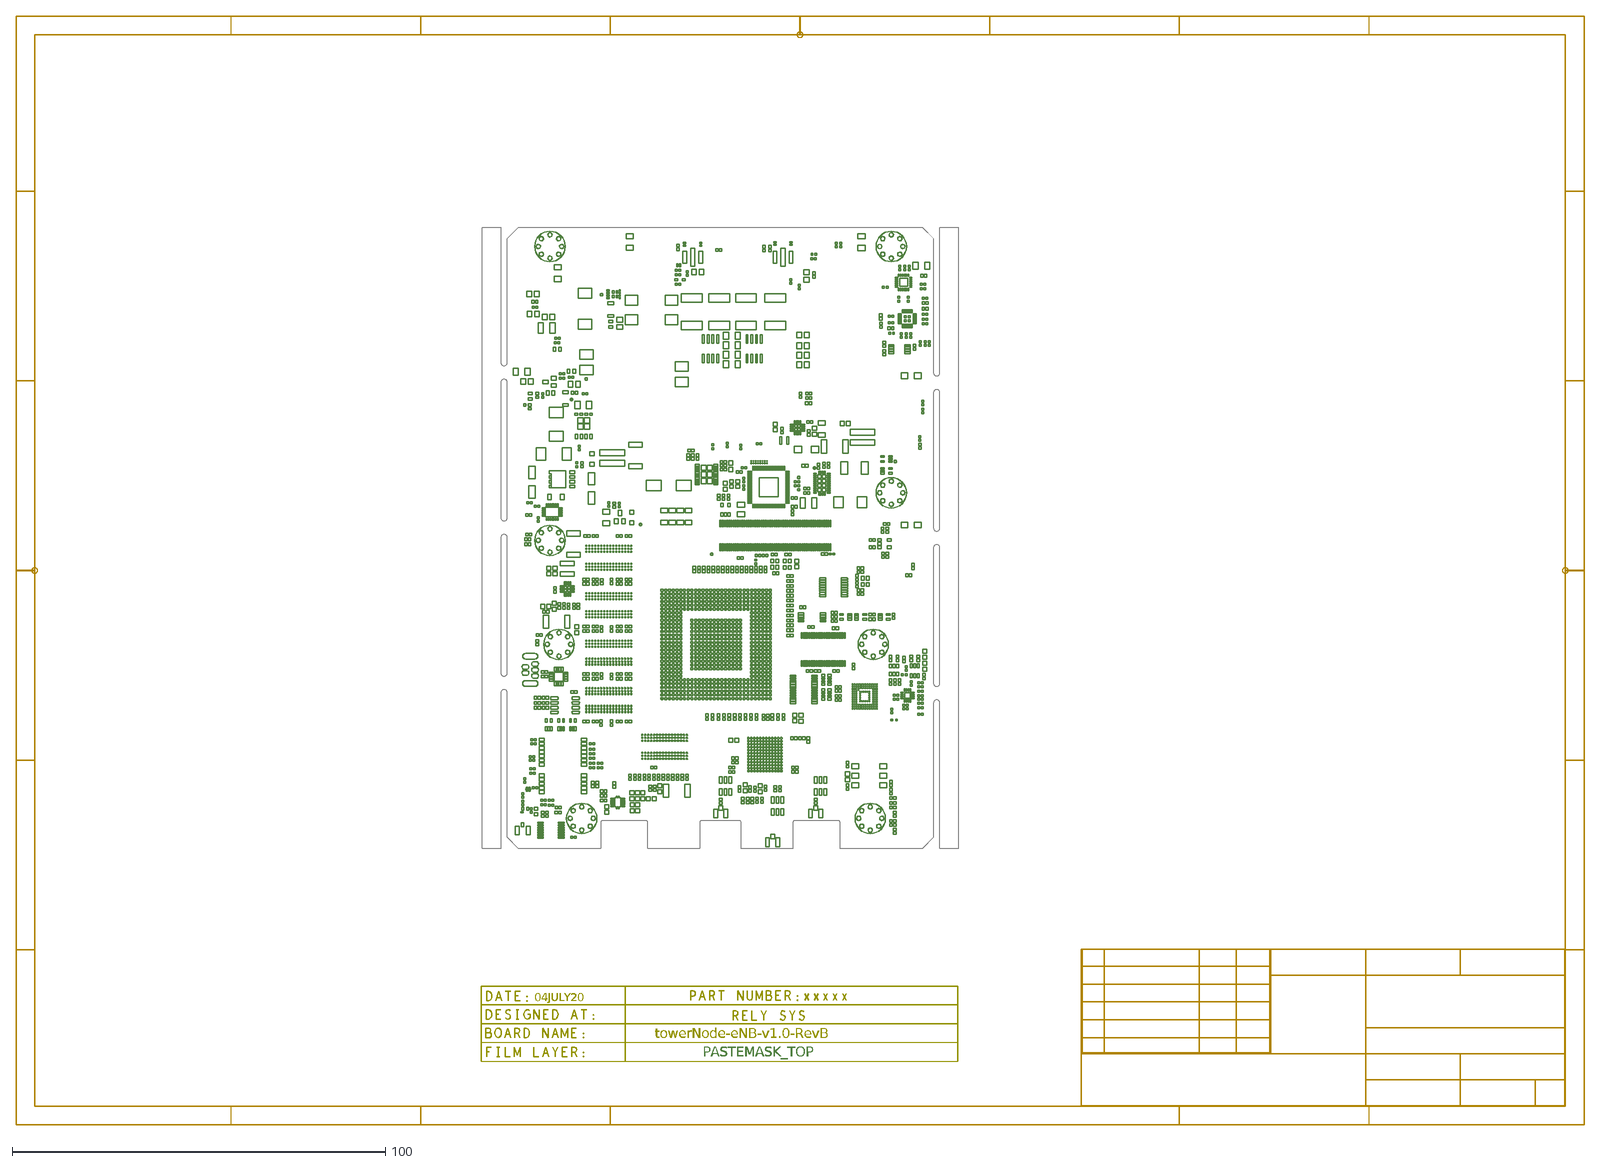
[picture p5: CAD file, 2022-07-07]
electronics/trx/stencil/trx_pmt.dxf
04JULY20
towerNode-eNB-v1.0-RevB
PASTEMASK_TOP

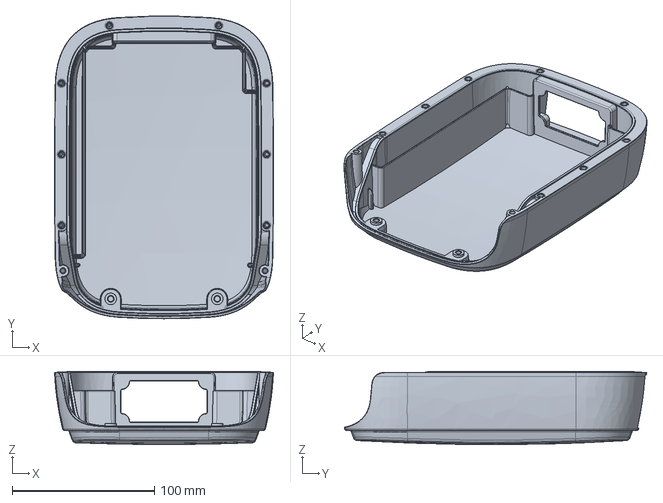
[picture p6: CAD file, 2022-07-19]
mechanics/nodes/tower/cad/top_tower_node.stp
154.2 x 213.0 x 51.4 mm

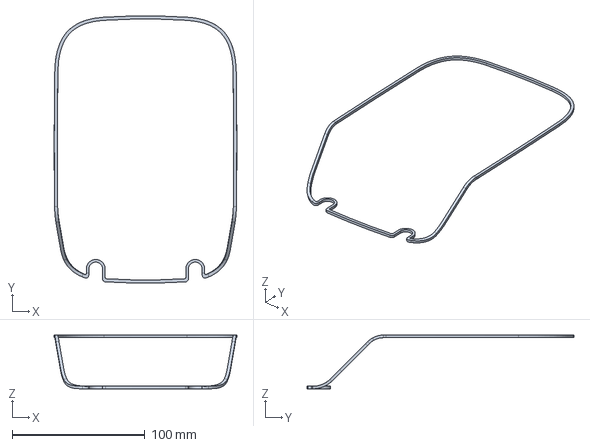
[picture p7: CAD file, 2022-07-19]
mechanics/nodes/tower/gaskets/gasket_tower_node.stp
137.7 x 201.3 x 40.6 mm

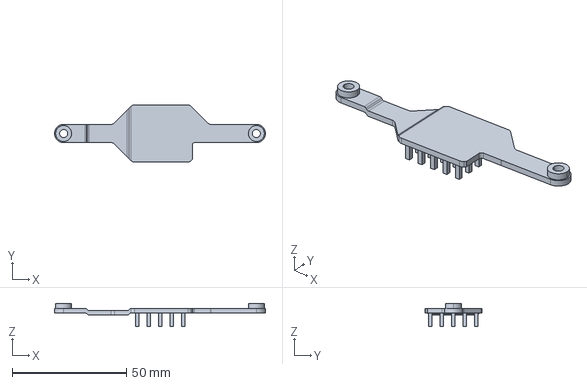
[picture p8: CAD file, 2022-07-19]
mechanics/nodes/tower/heatsinks/spreader_1.stp
92.2 x 25.0 x 10.2 mm

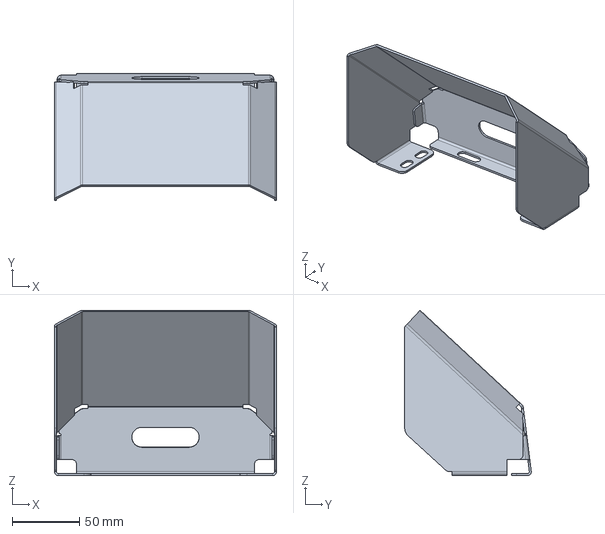
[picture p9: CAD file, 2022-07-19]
mechanics/solarcap/cad/solar_cap.stp
165.0 x 94.1 x 123.0 mm

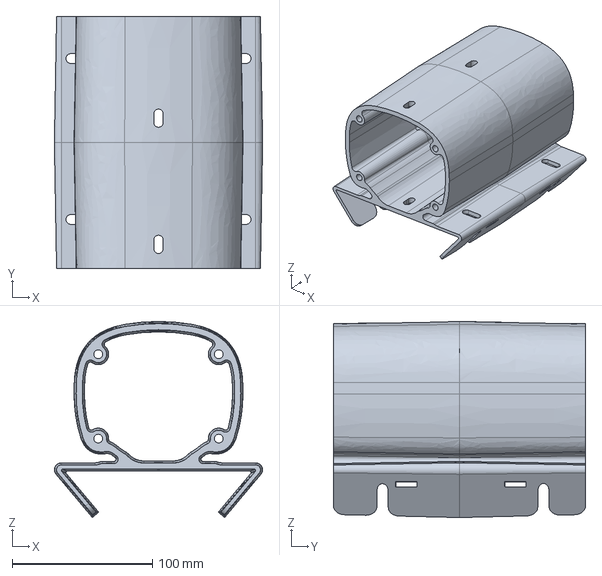
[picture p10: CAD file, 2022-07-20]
mechanics/units/amplifier/cad/mounting_amplifier_unit.stp
148.6 x 179.8 x 140.0 mm

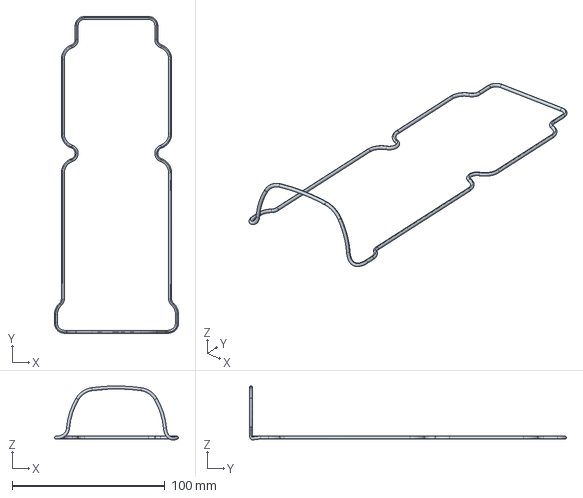
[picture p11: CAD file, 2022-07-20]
mechanics/units/amplifier/gaskets/gasket_amplifier_unit.stp
81.1 x 207.3 x 35.3 mm

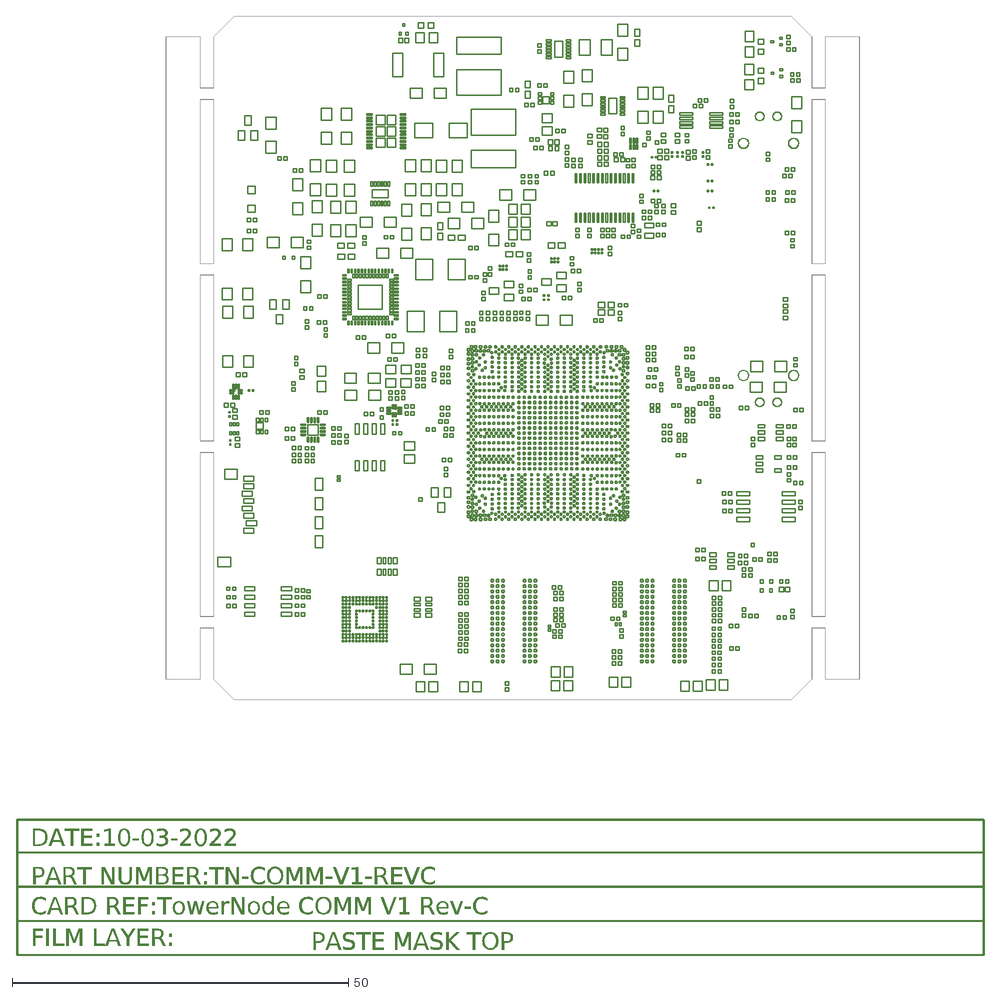
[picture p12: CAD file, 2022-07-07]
electronics/com/stencil/com_pmt.dxf
PASTE MASK TOP
FILM LAYER:
CARD REF:TowerNode COMM V1 Rev-C
DATE:10-03-2022
PART NUMBER:TN-COMM-V1-REVC

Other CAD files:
electronics/com/assembly/com_asb.dxf
electronics/mask/assembly/mask_asb.dxf
electronics/trx/assembly/trx_asb.dxf
modules/trx/assembly/trx_asb.dxf
electronics/com/assembly/com_ast.dxf
electronics/mask/assembly/mask_ast.dxf
electronics/mask/stencil/mask_stencil_pmt.dxf
electronics/mini_trx/assembly/mini_trx_asb.dxf
electronics/mini_trx/stencil/mini_trx_pmt.dxf
electronics/trx/assembly/trx_ast.dxf
electronics/trx/stencil/trx_pmb.dxf
mechanics/nodes/tower/cad/cup_tower_node.stp
mechanics/nodes/tower/heatsinks/spreader_2.stp
mechanics/nodes/tower/heatsinks/spreader_3.stp
mechanics/units/amplifier/cad/cup_amplifier_unit.stp
mechanics/units/amplifier/cad/mounting_cap_amplifier_unit.stp
modules/trx/assembly/trx_ast.dxf
modules/trx/stencil/trx_pmb.dxf

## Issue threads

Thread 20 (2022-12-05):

PoE subsystem to be changed

supreethsb, 2022-12-05:
Current PoE subsystem is based on Linear/Analog parts, which have availability issues and long lead time issues.

supreethsb, 2022-12-05:
Schematic creation is completed

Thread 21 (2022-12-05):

Hot swap controller to be replaced

supreethsb, 2022-12-05:
Replace Input protection IC (U246) with STEF12H60MAPUR from STMicroelectronics

https://www.st.com/en/power-management/stef12h60m.html#documentation

supreethsb, 2022-12-05:
Replace Input protection IC (U246) with STEF12H60MAPUR from STMicroelectronics

https://www.st.com/en/power-management/stef12h60m.html#documentation

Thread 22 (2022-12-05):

5V buck converter to be replaced

supreethsb, 2022-12-05:
Replace 5V buck converter (U8) with RT7299BHGQW from Richtek USA Inc

supreethsb, 2022-12-05:
Simulation results:

[https://app.zenhub.com/files/508029468/0ac6798f-37c5-49ff-94e3-617323306f3c/download](https://app.zenhub.com/files/508029468/0ac6798f-37c5-49ff-94e3-617323306f3c/download)

supreethsb, 2022-12-05:
Schematic update completed

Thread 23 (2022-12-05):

Replace 1.35V buck converter

supreethsb, 2022-12-05:

supreethsb, 2022-12-05:
Replace 1.35V buck converter (14) with RT5789BGJ8F from Richtek USA Inc.

https://www.richtek.com/Products/Switching%20Regulators/DC_DC%20StepDown%20Convertor/RT5789ART5789B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

supreethsb, 2022-12-05:
Schematic is updated

supreethsb, 2022-12-05:
Schematic is updated

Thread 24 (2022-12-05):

Replace LTE-SoC Core supply generator IC

supreethsb, 2022-12-05:

supreethsb, 2022-12-05:
Replace LTE-SoC core voltage supply DC-DC (U7) to MP8795HGLE-Z from MPS

https://www.monolithicpower.com/en/mp8795h.html

supreethsb, 2022-12-05:
Evaluation board details :
https://www.monolithicpower.com/en/documentview/productdocument/index/version/2/document_type/Datasheet/lang/en/sku/EV8795H-LE-00A/document_id/10274/

supreethsb, 2022-12-05:
Schematic is updated

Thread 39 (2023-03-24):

TDD Switching Issue-B48/B41/B40

Sharabu-Naveen, 2023-03-24:

Sharabu-Naveen, 2023-03-28:
Test Case 1:-I Tested the FDD mode and to make sure  system is working fine .
Observation:- ETM is running fine and logs are captured(FDD_logs)
Test Case-2: tested with the TDD binaries and changed the DUPLEXMODE =TDD
Observation: ETM is not running and logs are captured(TDD_logs_1)

Test case 3:- With new binaries and configuration files we tested e2e call in TDD mode we observed spectrum is switching in the Evaluation module anlayzer , but the TX/RX switching pin and duplex registers still showing in FDD .

Need to check the same setup in LTE TDD spectrum analyzer and EVM to make sure TDD E2E is working fine

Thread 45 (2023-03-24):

Carrier Board for COM SMARC module - Schematic

supreethsb, 2023-03-24:
Make Carrier Board Schematic for SMARC module

supreethsb, 2023-03-29:
COM carrier board schematic is completed

supreethsb, 2023-03-30:
Updated schematic is saved in below path:

\GDrive\Ukama Files Repository\04_Hardware\1.TowerNode\2.COMM\1.Schematics\Carrier

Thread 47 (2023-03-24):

Ethernet not consistent

Sagar281, 2023-03-24:
Ethernet communication seems to be inconsistent,some packets getting dropped when iperf is performed.

**Root Cause:** To be Identified

**Next Step/Observations:**

Need to Identify if the issue is between RJ45 connector and ethernet switch OR between Ethernet switch and LTE-SoC.
To check the integrity between RJ45 and ethernet switch, ethernet conpliance test/eye diagram analysis to be performed.
If above possibility is ruled out, then the issue is between ethernet switch and LTE-SoC. To dubug further, all SGMII/SERDES register values to be verified.

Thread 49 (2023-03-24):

POE input not working in Board #3

Sagar281, 2023-03-24:
Input supply voltage is not coming upto PC Controller.

**Root cause:**
Bridge rectifier to be checked.

**Next Step/Observations:**
Short is observed at bridge rectifier IC supply voltage because of this, PC Controller is not working.

**Resolution:**
Bridge rectifier IC to be replaced.

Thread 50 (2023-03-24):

Check if POE is working

Sagar281, 2023-03-24:
For TRX Rev C board, only power section is populated first and POE is validated.

**Observations:**
Check if 55V is coming
Check if PC controller is working.

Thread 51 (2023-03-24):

Validate Regulators

Sagar281, 2023-03-24:
TRX Rev C - Only power section will be populated first, all the regulators are validated as listed below:
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

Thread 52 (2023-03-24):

PCB Assembly - Rev C TRX

Sagar281, 2023-03-24:
Get the power section of TRX Rev C board assembled, assembly house and No of boards yet to be finalized.

**Next Steps/Observation:**
- Quotation from Screaming Ckts, Oregon has been received.
- Team to finalize the CM and No of boards to be assembled.

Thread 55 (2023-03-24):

Get the Test Setup Ready

Sagar281, 2023-03-24:
**Next Steps/Observations:**
- Procure Automation testing BOM items and handover to Jig manufacturer for integration and testing.
- Get few boards made(Fab+Assbly) with test points incorporated ,this will be useful for Jig manufacturer for testing the Jig.

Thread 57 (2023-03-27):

Incorporate Design feedback from Microchip on main-Brick design

supreethsb, 2023-03-27:
Microchip has provided few recommendations based on their design review of main-Brick board related to Ethernet switch section. Comments are uploaded below:

https://docs.google.com/document/d/1qNinUSDOoD2_SNO-bNP0tD22ZNz0NH9P/edit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

supreethsb, 2023-03-27:
Schematic and layout update is pending

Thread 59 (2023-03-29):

Manufacturing package for all of our boards

markhor, 2023-03-29:
We need to assemble manufacturing packages for all the boards (TRX, FEM, CTRL) including BRICK and ME.

Sagar281, 2023-03-29:
Added Mechanical Manufacturing design files to the repository at below link:
https://drive.google.com/drive/folders/1jh8l6DeWw8oI97za0SmEmWuwRfyjovAU?usp=share_link

supreethsb, 2023-03-30:
Uploaded TRX files in below path:
GDrive\Ukama Files Repository\04_Hardware\1.TowerNode\1.eNB\10.Manufacturing package\RevC

Main brick files are uploaded to:
GDrive\Ukama Files Repository\04_Hardware\6.Brick\main Brick\Manufacturing Package

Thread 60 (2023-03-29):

Prepare all the modules for DFM

supreethsb, 2023-03-29:
List out all the potential access points for DFM.
Include test points to measure impedance/voltage as part of Manufacturing testing in the design.

Need to ensure the test coverage is 100% which includes, power, interfaces, memories, modules, mechanical interface etc.

Above points will be applicable for below boards:

- [ ] towerNode : TRX
- [ ] towerNode : COM
- [ ] AmplifierUnit : Controller
- [ ] AmplifierUnit : Band3 FEM
- [ ] AmplifierUnit : Band41 FEM
- [ ] AmplifierUnit : Band48 FEM
- [ ] Brick : Main
- [ ] Brick : Mini-Ethernet
- [ ] Brick : Mini-Cellular

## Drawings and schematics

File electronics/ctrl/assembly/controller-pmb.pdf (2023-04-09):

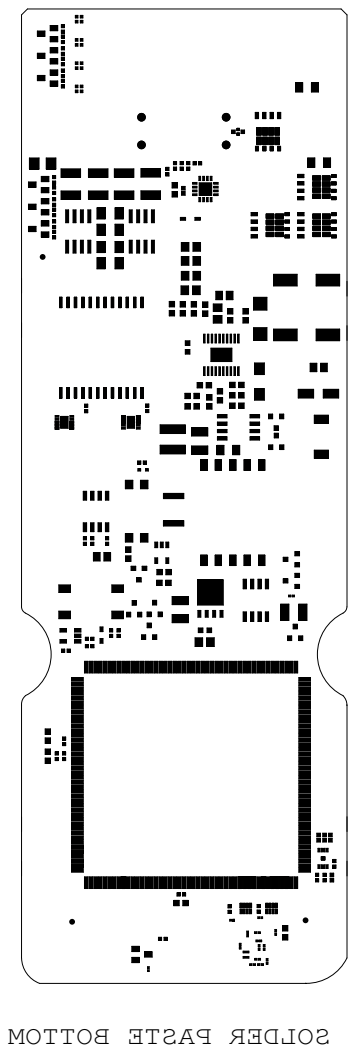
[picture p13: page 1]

SOLDER PASTE BOTTOM

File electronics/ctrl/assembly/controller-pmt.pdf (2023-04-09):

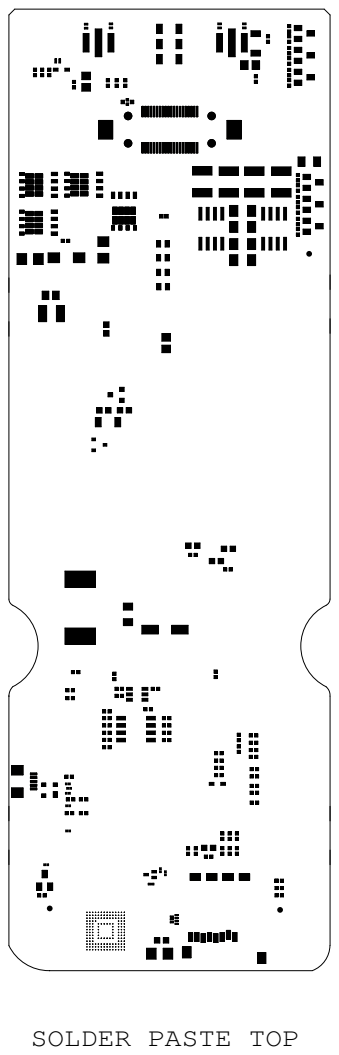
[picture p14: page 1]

SOLDER PASTE TOP

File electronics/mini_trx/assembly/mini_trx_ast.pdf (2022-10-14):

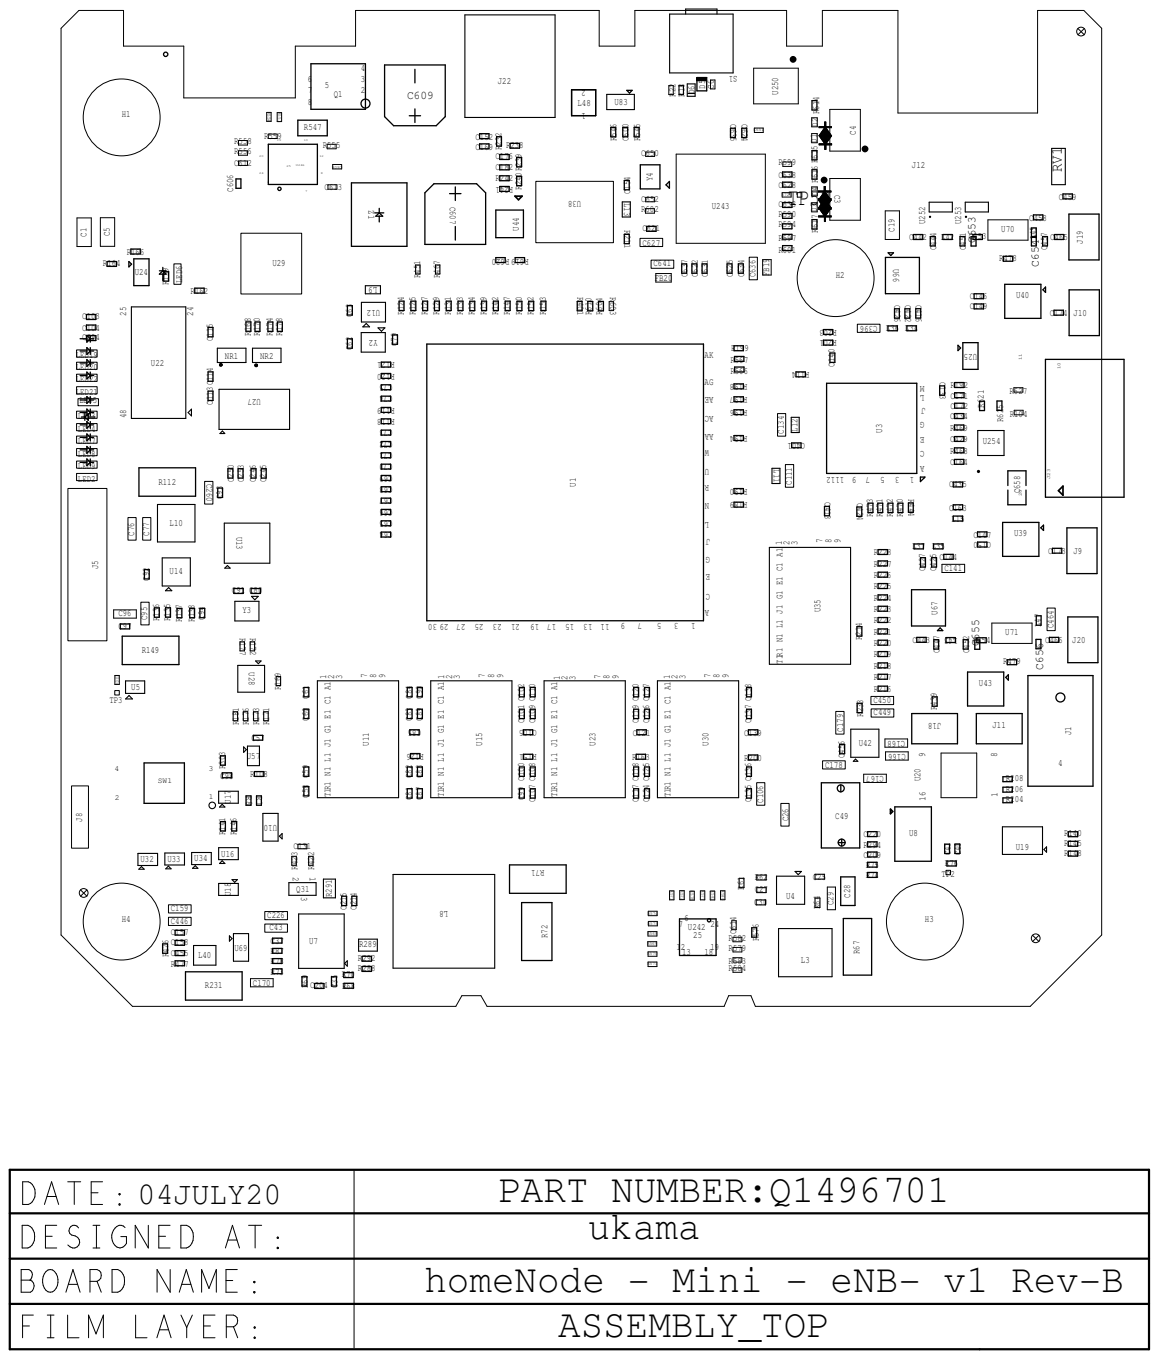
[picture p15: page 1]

PART NUMBER:Q1496701
ukama

homeNode - Mini - eNB- v1 Rev-B

ASSEMBLY_TOP

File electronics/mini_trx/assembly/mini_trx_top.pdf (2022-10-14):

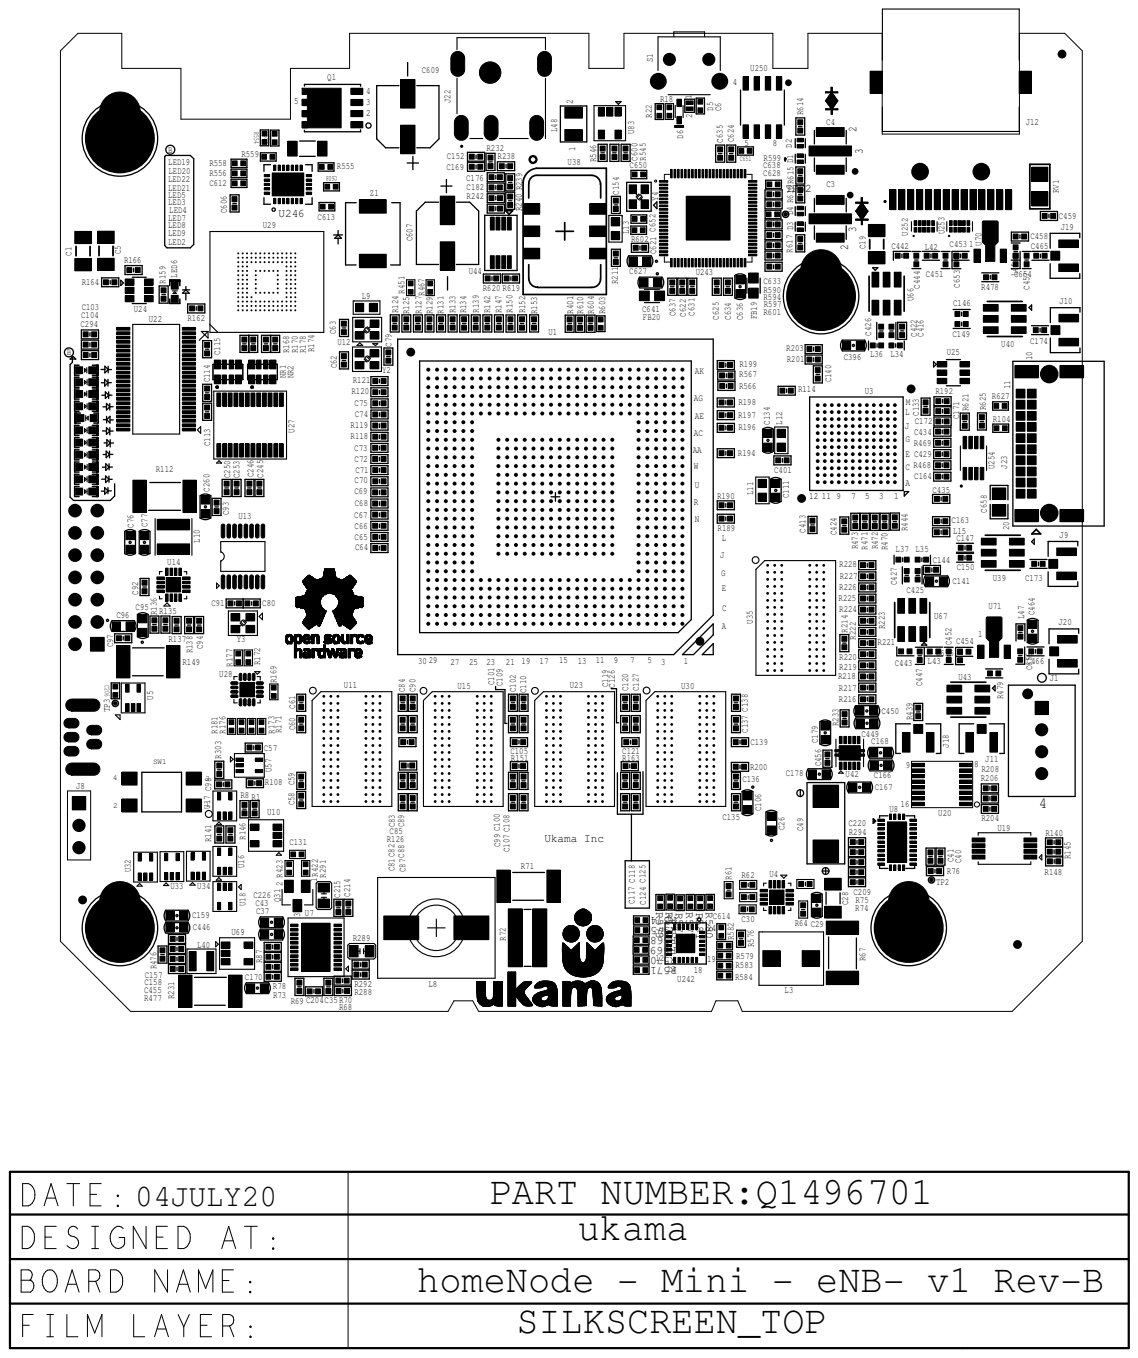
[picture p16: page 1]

PART NUMBER:Q1496701
ukama

homeNode - Mini - eNB- v1 Rev-B

SILKSCREEN_TOP

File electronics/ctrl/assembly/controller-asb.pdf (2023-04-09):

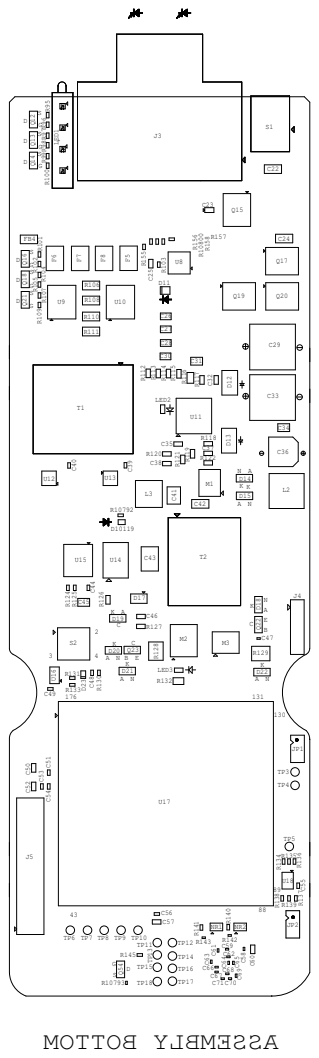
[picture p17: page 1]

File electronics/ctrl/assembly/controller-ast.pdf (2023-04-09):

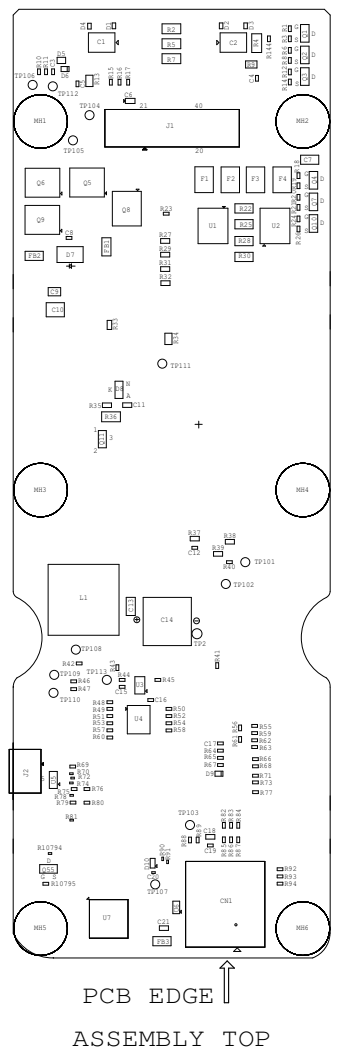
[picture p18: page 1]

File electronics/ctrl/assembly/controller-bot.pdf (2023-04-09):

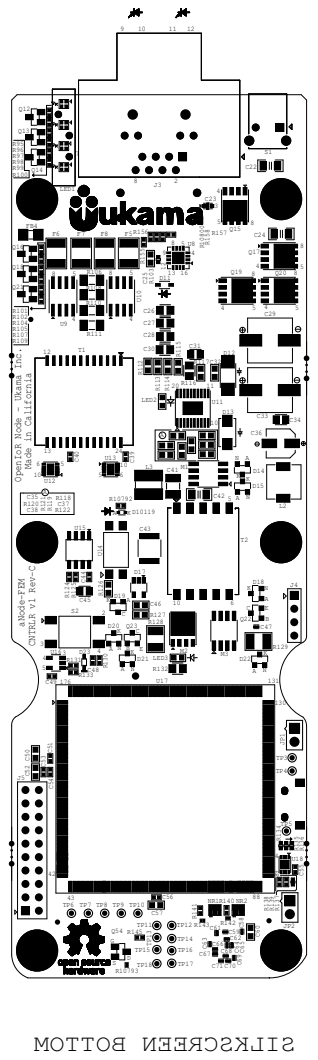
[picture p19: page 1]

OpenIoR Node - Ukama Inc. aNode-FEM

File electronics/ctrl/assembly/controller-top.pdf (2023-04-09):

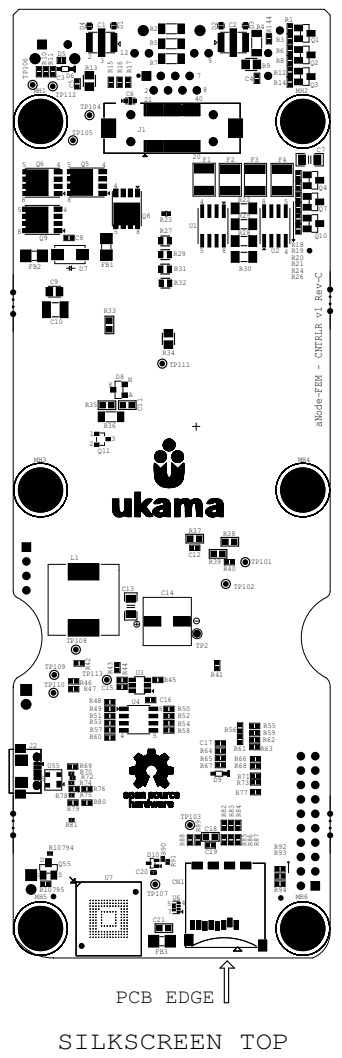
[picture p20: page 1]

aNode-FEM - CNTRLR v1 Rev-C

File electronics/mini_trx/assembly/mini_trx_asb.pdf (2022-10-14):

TP53

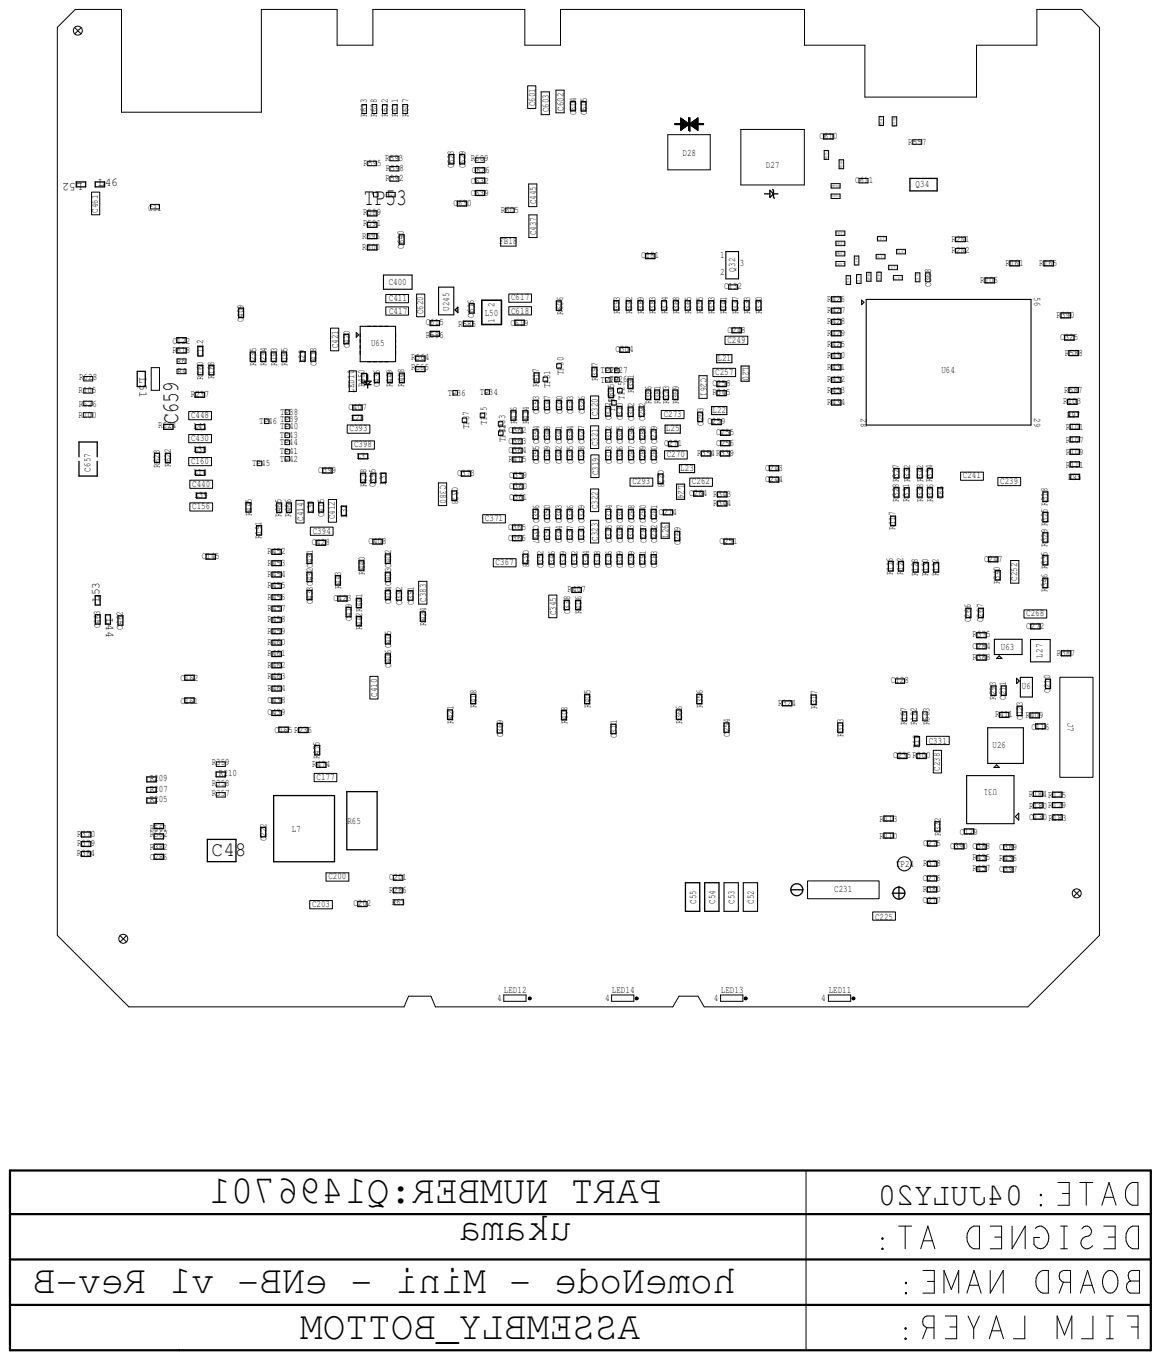
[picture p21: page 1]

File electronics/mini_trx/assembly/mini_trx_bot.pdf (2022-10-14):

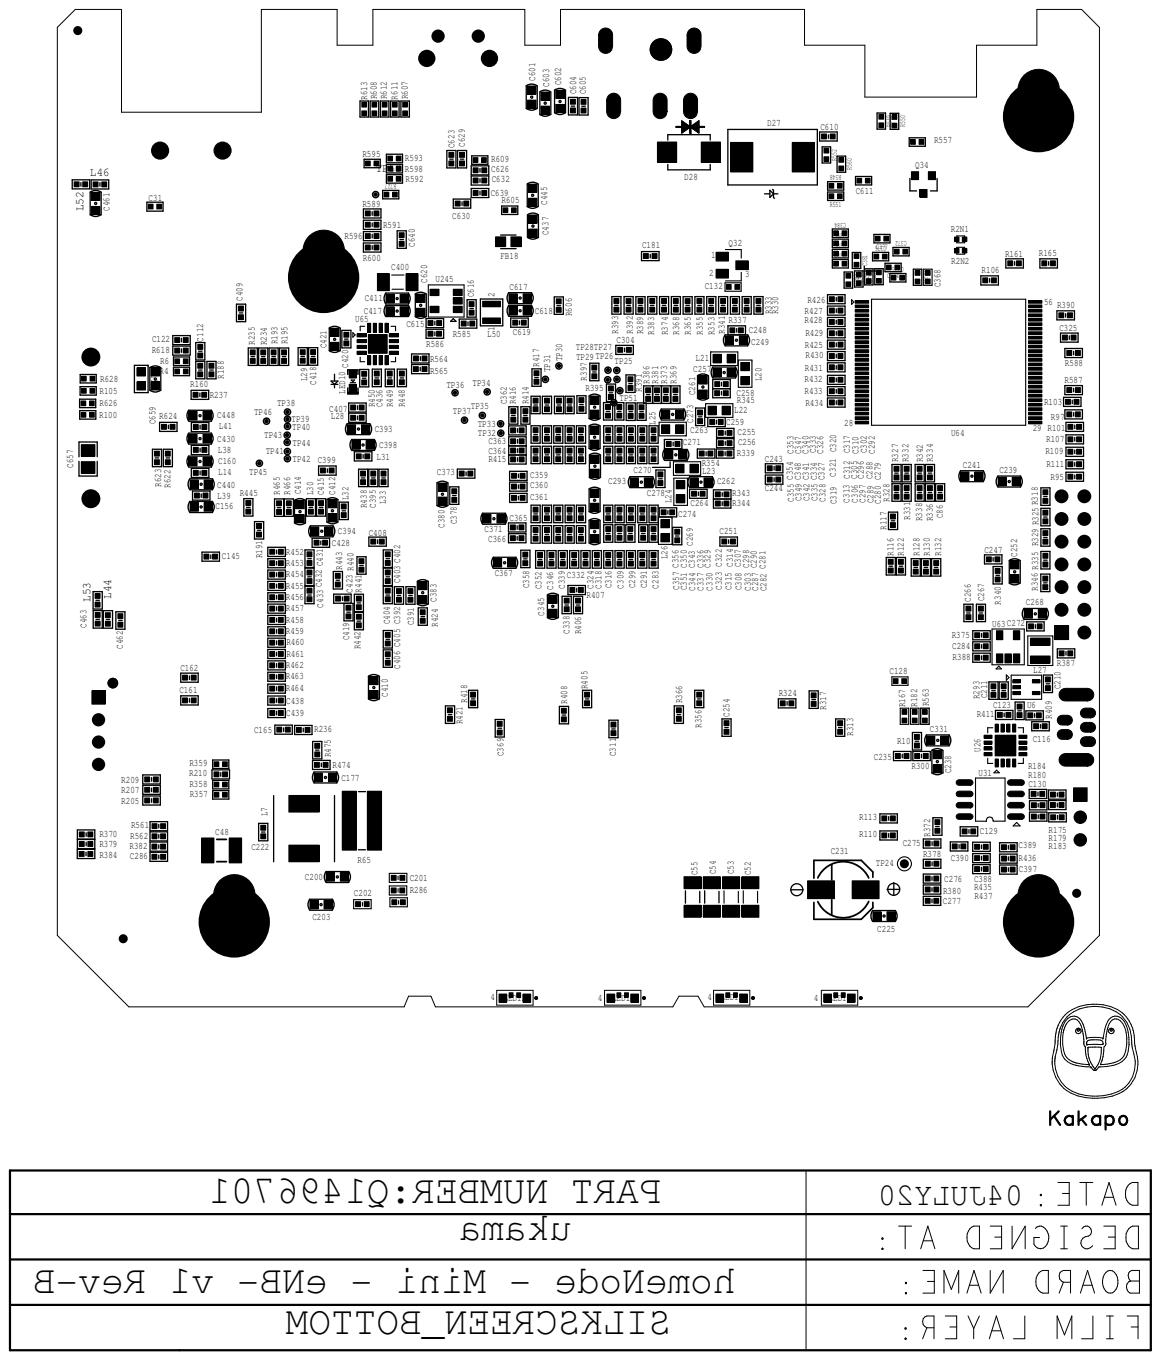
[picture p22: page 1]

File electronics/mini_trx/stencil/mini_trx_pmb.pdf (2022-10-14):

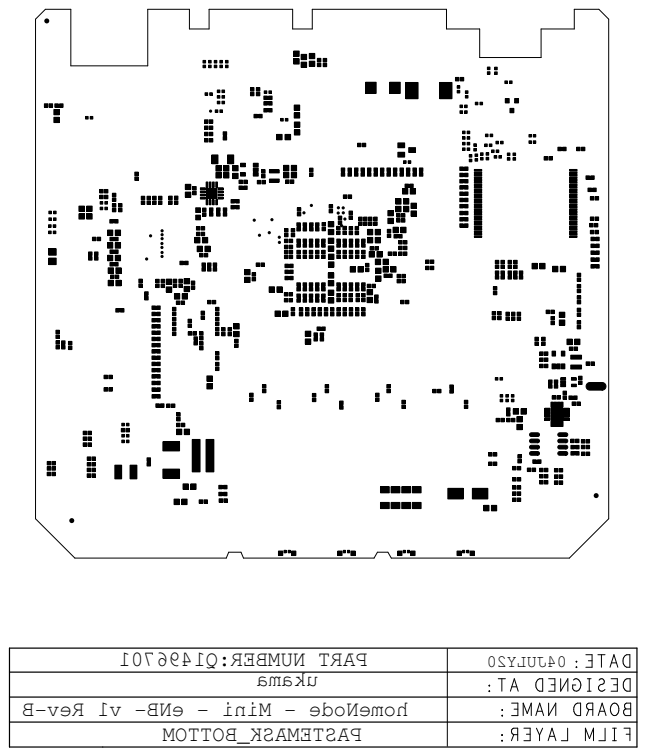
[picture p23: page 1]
04JULY20; PART NUMBER:Q1496701 ukama; PASTEMASK_BOTTOM

homeNode - Mini - eNB- v1 Rev-B

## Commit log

2022-07-03 first commit of electronics and hardware of Ukama nodes
    [COM_V1_P2-1-10.drl, COM_V1_P2-ASB.gbr, COM_V1_P2-AST.gbr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]
2022-07-07 add assembly, placement and stencil files for trx module
    [trx_asb.dxf, trx_ast.dxf, trx_pmb.dxf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]
2022-07-07 Rename electronics -> modules
    [COM_V1_P2-1-10.drl, COM_V1_P2-ASB.gbr, COM_V1_P2-AST.gbr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]
2022-07-07 update 'com' module assembly, stencil, schematic and placement files
    [COM_V1_P2_ASB.dxf, COM_V1_P2_AST.dxf, com_asb.dxf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]
2022-07-07 add mask module
    [mask-C2-RevC-1-4.drl, mask-C2-RevC_ASB.gbr, mask-C2-RevC_AST.gbr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]
2022-07-19 Add Tower node drawings, cad, assembly, bom, etc.
    [bom_tower_node.csv, bom_tower_node.xlsx, cup_tower_node.stp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]
2022-07-19 add stp files for heat spreaders
    [spreader_1.stp, spreader_2.stp, spreader_3.stp]
2022-07-19 Add solarcap for tower node
    [solar_cap.stp]
2022-07-19 Add first version of mounting brackets
2022-07-20 Add amplifier node artwork, assembly, bom, cad, drawing, etc
    [amplifier_node_bom - amplifier node.csv, amplifier_node_bom.xlsx, cup_amplifier_node.stp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]
2022-07-20 add doc structure for com module
    [amplifier_node_bom.csv]
2022-08-09 TRX doc update
    Updated specs, architecture, power, clock/reset sections
2022-08-17 TRX doc update
    Updated specs and power tree
2022-08-17 memory
    updated memory, power sections
2022-10-12 dir re-structuring
    [COM_V1_P2-1-10.drl, COM_V1_P2-ASB.gbr, COM_V1_P2-AST.gbr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]
2022-10-13 Rename mechanicals -> mechanics
    [cup_amplifier_unit.stp, cup_tower_node.stp, gasket_amplifier_unit.stp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]
2022-10-14 Add mini-trx module
    [mini_trx_asb.dxf, mini_trx_ast.dxf, mini_trx_bom.xlsx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]
2023-04-09 RevC updates
    Controller board RevC design files updated with test pads required for Manufacturing tests.
    [controller_schematic.dsn, controller_schematics.DSN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]
